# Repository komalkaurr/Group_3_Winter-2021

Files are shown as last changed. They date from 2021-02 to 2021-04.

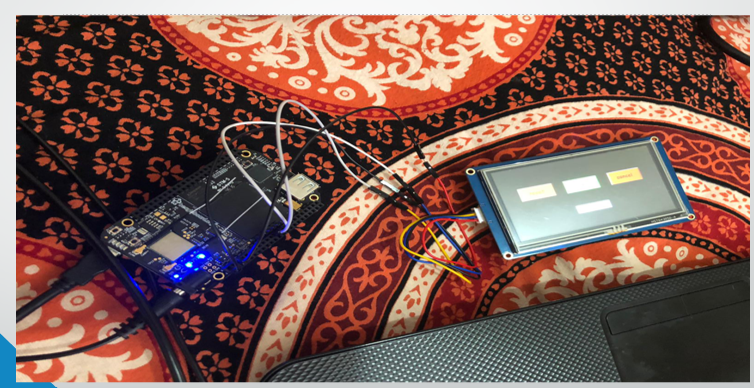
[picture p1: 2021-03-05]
Interfacing touch screen display/Connection .png

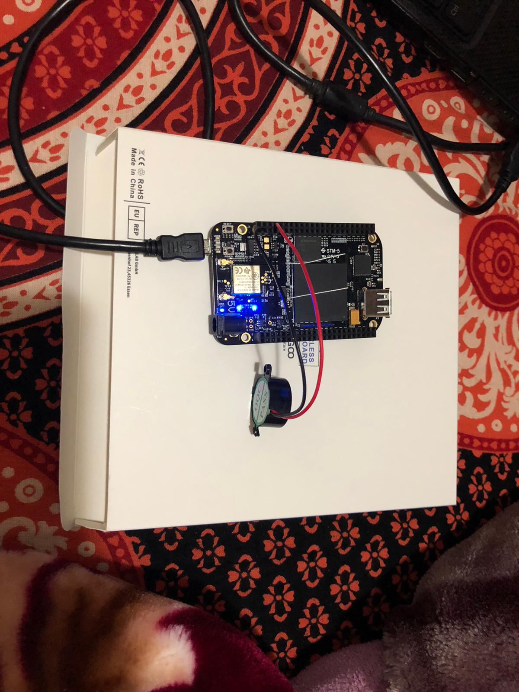
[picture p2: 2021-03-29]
Interfacing of buzzer with BB-WI/Connection.jpeg

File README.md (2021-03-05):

# Group_3_Winter-2021
EMBT Term 4 ESE_4009_2_Embedded Systems Engineering Project Group_3 

Group Members:
Komal Preet Kaur(c0765526)
Ramandeep Kaur(c0772741)
Amit Kumar(c0772515)
Ashok Kumar Saini(c0762216)
Sagar Pasricha(c0765531)
Virender Singh(c0762540)

EMBT is a core Embedded Sytems Design Course which prepare us for future in Embedded technology. In first 3 semesters, we learned about various theoretical aspects of Embedded Engineering and Design techniques. 
In 3rd semester, in ESE_3025 , we learned about real time operating systems and in ESE_3005,we learned about embedded systems architecture, LPC1769 board and MCUExpresso, various architectures such as mutex etc.Thus, we have learned about BBB and in 3014 ,we learned about various communication protocols and how to implement them with BBB to communicate with various devices. 
In term 4, we will make use of all the software and hardware skills in Capstone project. Our central device will be BB Wireless and we will make use of some real time problems in order to make a project which can tackle these issues to some extent.
In Term 4, we are going to design an IoT based smart restauranrt food ordering menu using Beaglebone black wireless.
Smart Restaurant food ordering menu using Beaglebone black.
1) Deciding and buying the components:
2) 2 Beaglebone
3) Arduino UNO
4) GSM module (SIM 900)
5) Xbee S2C RF module (Rx and Tx)
6) 20*4 LCD Module
7) 4.3" cape LCD touch screen (Nextion)
8) Breadboard/Zero PCB
9) 2 SD cards (32GB each)
10) Jumper wires
11) Power supply (Adapter)
12) Soldering Equipment (soldering iron, soldering wire)
13) Carbon Monoxide detection sensor 
14) Temperature Sensor (LM 35)
15) Smoke and LPG gas sensor (MQ-2)
16) Mct2e optocoupler
17) Buzzer
18)  Wire cutter
19) Wire stripper
20) 12v DC Fan
21) Power supply

**Testing hardware components:
After buying all hardware, first step is to test it so that we can use it in our project with no second thoughts. 

**So, I was assigned a task to test following components:

Arduino Uno: I tested Arduino Uno with blinking LED code avilable in Arduino IDE and also researched about Arduino IDE

20* 2 LCD module : For testing of LCD, I interfaced LCD module to Arduino Uno and imported I2C library to IDE and tested an example code from library

4.3" Nextion Touch display module: For testing of touch module, I created a simple GUI using Nextion editor and then in order to show data transfer between Arduino and touch LCD, 
I imported a code to Arduino IDE and uploaded it to Touch module and it worked properly.

Smoke sensor-MQ-2 : Testing of smoke sensor is done by interfacing it with arduino

CO sensor-MQ-9 : It is also interfaced to Arduino in order to do testing.

Magnetic Buzzer: Buzzer is also tested using a simple delay program in Arduino IDE

SIM900 GSM Module :I interfaced GSM Module to Arduino but it was not able to detect network , so testing was not completed.

I was able to test all components succesfully except GSM module. 

Next Task:
My task is about interfacing of touch screen dsiplay with Beaglebone Black Wireless.

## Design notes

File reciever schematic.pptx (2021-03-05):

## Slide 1

Designing circuit diagram and schematics for receiver side

Sagar Pasricha (C0765531)

## Different Software's used for circuit designing

- Circuit Maker
- Microsoft Visio
- Easy EDA
- Fritzing
- Eagle
- OrCAD
- gEDA
- SmartDraw
- KiCad
- CircuitLab
- XCircuit

## Easy EDA

- Easy EDA is a web based EDA tool that enables the hardware engineers to design, simulate, share and discuss schematics, simulations and printed circuit boards. Features may include Bill of Materials, Gerber files and pick and place files and documentary outputs in PDF, PNG and SVG formats.
- Most of the things, such as libraries, projects, custom-made parts, packages and shared files are accessible via a simple drop down menu at the top left side of the software interface. This makes it easy for you to navigate through the software regardless of whether you are beginner or pro.

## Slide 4

Beaglebone black wireless

Based on the extremely successful open-source BeagleBone Black hardware design, BeagleBone Black Wireless is a high-expansion, maker-focused, community-supported open hardware computer created by the BeagleBoard.org Foundation.
512MB DDR3 RAM
4GB 8-bit eMMC on-board flash storage
3D graphics accelerator
NEON floating-point accelerator
2x PRU 32-bit microcontroller

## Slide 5

Beaglebone black wireless

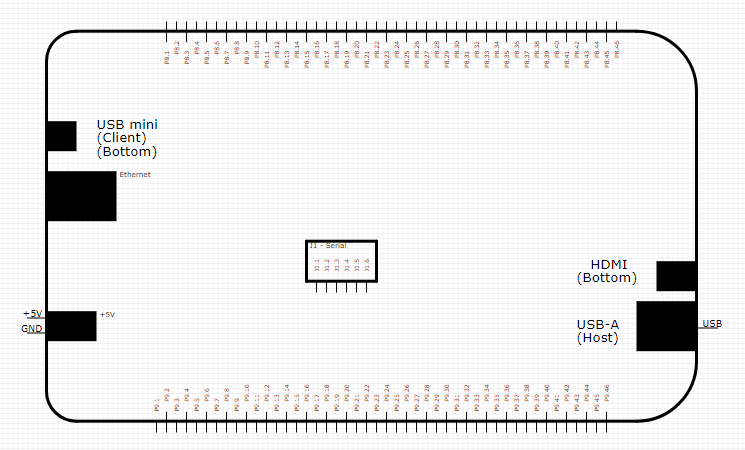
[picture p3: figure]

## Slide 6

Buzzer interfacing

For interfacing buzzer, GPIO pins of BBB are used.
A buzzer or beeper is an audio signaling device, which may be mechanical, electromechanical, or piezoelectric. Typical uses of buzzers and beepers include alarm devices, timers and confirmation of user input such as a mouse click or keystroke.

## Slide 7

Buzzer interfacing

BBB | Buzzer
1 (DGND) | -V
23 (GPIO_49) | +V

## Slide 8

Buzzer interfacing

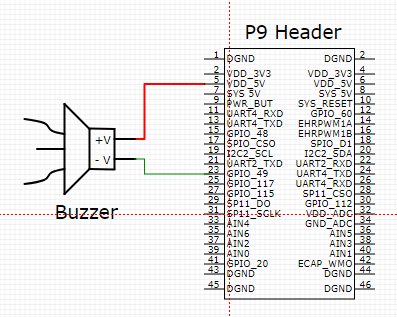
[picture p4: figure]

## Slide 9

Gas & SMOKE sensor interfacing

SPI or I2C protocol can be used to interface LPG sensor via GPIO pins of BBB. There is possible schematics where the gas sensor is connected to 5V power supply at a BeagleBone Black's analog input pin.

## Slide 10

Gas & SMOKE sensor interfacing

BBB | MQ2 Sensor
1 (DGND) | GND
5 (VDD 5V) | Vcc
33 (AIN4) | Vout

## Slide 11

Gas & SMOKE sensor interfacing

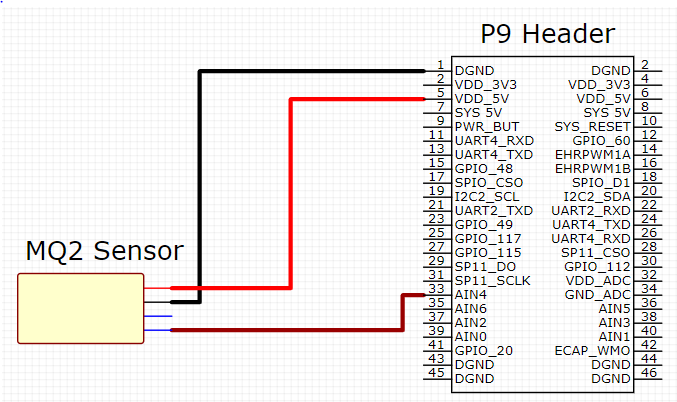
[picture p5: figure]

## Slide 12

GAS & smoke sensor interfacing

BBB | MQ6 Sensor
2 (DGND) | GND
6 (VDD 5V) | Vcc
36 (AIN5) | Vout

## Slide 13

GAS & smoke sensor interfacing

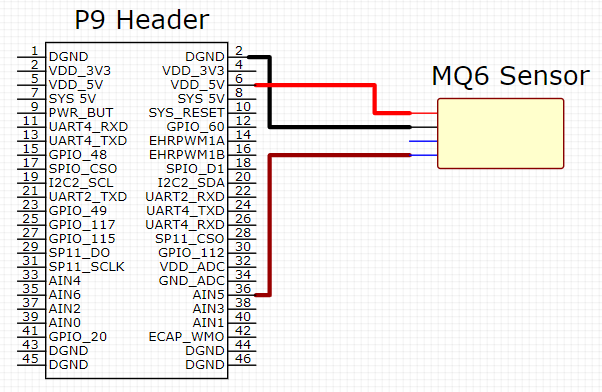
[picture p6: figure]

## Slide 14

temperature sensor
interfacing

LM35 is an analog sensor (Temperature Sensor) which measures the temperature and linear output given in voltage form. ADC is required to convert analog output of temperature sensor to digital output. Since BBB has an on chip ADC, we can directly interface these two.

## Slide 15

temperature sensor
interfacing

BBB | LM35 Sensor
1 (DGND) | GND
5 (VDD +5V) | Vcc
38 (AIN3) | Vout

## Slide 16

temperature sensor
interfacing

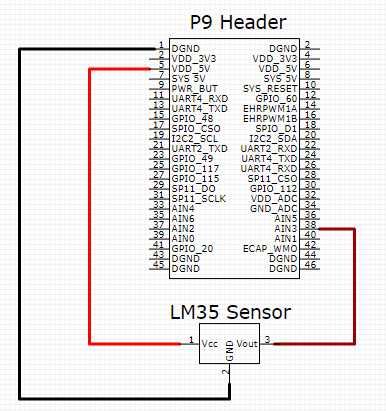
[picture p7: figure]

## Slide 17

dc fan interfacing

One of the GPIO pin of BBB is connected to the Opto-coupler’s photodiode pin which lets the inner circuit to switch on (closed circuit) and we can connect the other end to the Fan.

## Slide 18

dc fan interfacing

BBB | Optocoupler | DC Fan
15 (GPIO_48) | 1 (Photodiode)
45 (DGND) | 2 (Photodiode)
| 4 (Vout) | Red
| 5 (+9V)

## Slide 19

dc fan interfacing

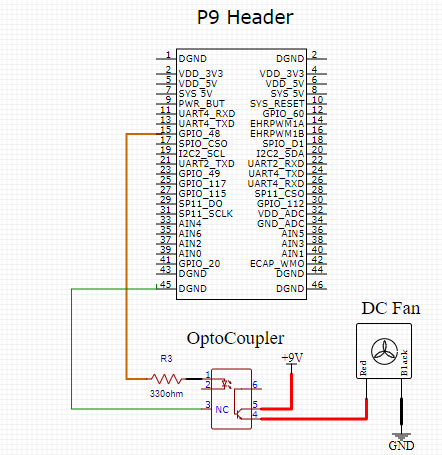
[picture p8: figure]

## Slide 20

Xbee interfacing

For a microcontroller based project, communication is necessary between devices. In our project we need two-way communication, so we use XBee trans-receiver which can transmit and receive data at the same time.

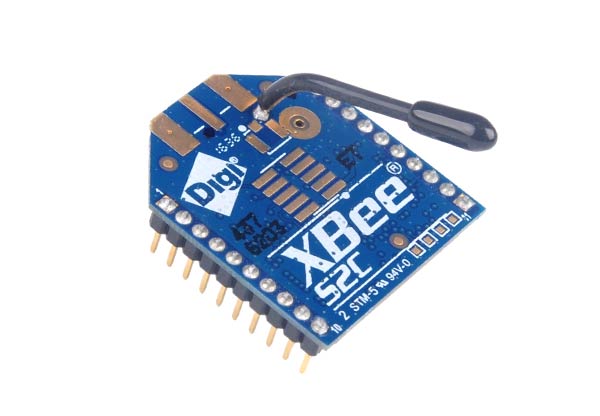
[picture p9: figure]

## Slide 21

Xbee interfacing

Pin Interface with Beaglebone Balck Wireless:

BBB | XBee
6 (Vdd +5V) | 1 (Vcc)
22 (UART_RxD) | 2 (Dout)
24 (UART4_TxD | 3 (Din)
46 (DGND) | 10 (GND)

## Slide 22

Xbee interfacing

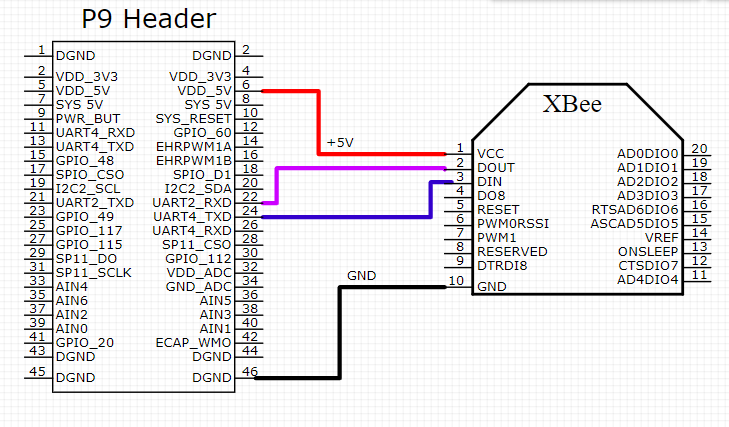
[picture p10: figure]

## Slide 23

Gsm module interfacing

The SIM900 is a complete Quad-band GSM/GPRS solution in a SMT module which can be embedded in the customer applications. Featuring an industry standard interface, the SIM900 delivers GSM/GPRS 850/900/1800/1900MHz performance for voice, SMS, data and fax.
SIM900 is designed with a very powerful single-chip processor integrating AMR926EJ-S core
We have interfaced GSM module to Beaglebone via Arduino.

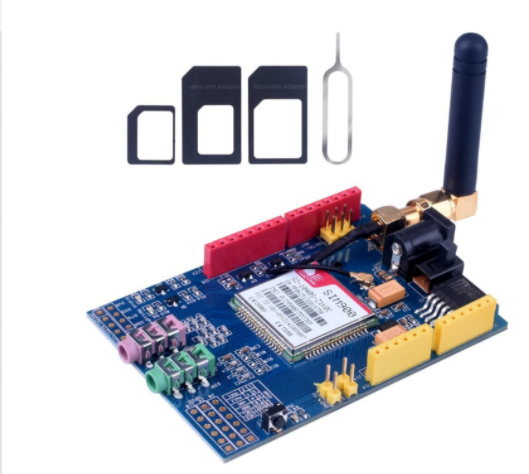
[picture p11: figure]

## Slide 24

Gsm module interfacing with arduino

Arduino | GSM Module
D_0 | TX (Transmitter)
D_1 | Rx (Receiver)
GND2 | GND
5V | 5V

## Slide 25

Arduino interfacing with Beaglebone:

Arduino | Beaglebone
D_6 | 26(UART_4RXD)
D_7 | 24(UART_4TXD
GND2 | GND
5V | 5V

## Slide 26

Gsm module interfacing

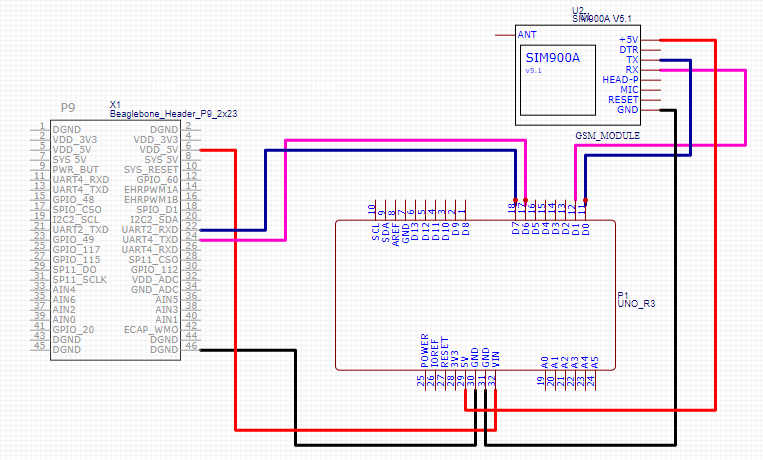
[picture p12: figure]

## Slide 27

I2c lcd interfacing

LCD (Liquid Crystal Display), In order to interface BBB to LCD ,GPIO pins of Beaglebone are used. Before installing the character LCD library you'll need to make sure a few dependencies are installed On the BeagleBone Black.
Firstly, we need to interface I2C module with Beaglebone Black wireless including supply voltage.
Then LCD is connected to I2C module including supply and data pins.

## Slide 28

I2c lcd interfacing

BBB | I2C Module
2 (DGND) | 17 (GND)
6 (Vdd +5V) | 18 (Vcc)
19 (I2C2_SCL) | 19 (SDA)
20 (I2C2_SDA) | 20 (SCL)

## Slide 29

I2c lcd interfacing

I2C Module | LCD
1 (VSS) | 1 (VSS)
2 (VDD) | 2 (VDD)
3 (V0) | 3 (V0)
4 (RS) | 4 (RS)
5 (R/W) | 5 (R/W)
6 (E) | 6 (E)
7-14 (DB0-DB7) | 7-14 (DB0-DB7)
15 (A) | 15 (BLA)
16 (K) | 16 (BLK)

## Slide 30

I2c lcd interfacing

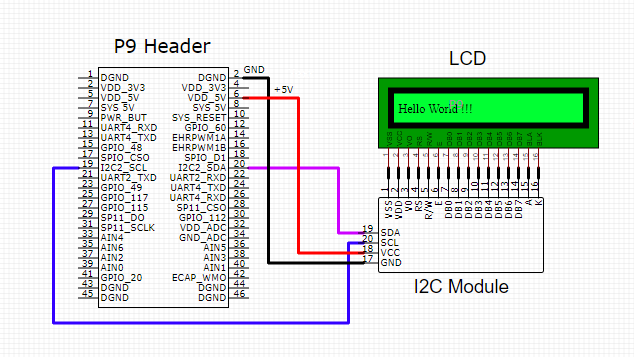
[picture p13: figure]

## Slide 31

Receiver circuit

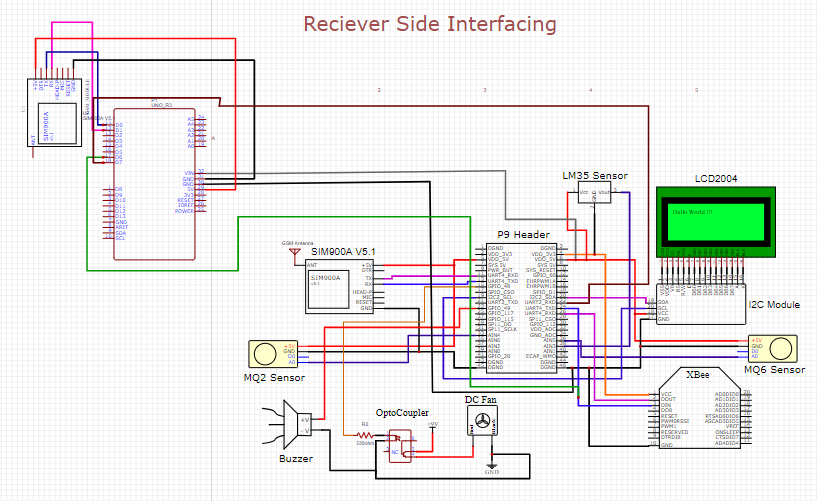
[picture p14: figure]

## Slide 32

references

- EasyEDA tutorial. Retrieved from easyeda.com: https:// (https://docs.easyeda.com/en/FAQ/Editor/index.html)docs.easyeda.com/en/FAQ/Editor/index.html
- turn on-off a 12V cpu fan with optocoupler. (n.d.). Retrieved from stackexchange.com: https:// (https://electronics.stackexchange.com/questions/154119/arduino-turn-on-off-a-12v-cpu-fan-with-optocoupler)electronics.stackexchange.com/questions/154119/arduino-turn-on-off-a-12v-cpu-fan-with-optocoupler
- MQ2 Gas Sensor. (2018, jan 04). Retrieved from components101.com: https:// (https://components101.com/mq2-gas-sensor)components101.com/mq2-gas-sensor
- DiCola, T. (n.d.). Character LCD with Raspberry Pi or BeagleBone Black. Retrieved from www.digikey.ca: https:// (https://www.digikey.ca/en/maker/projects/character-lcd-with-raspberry-pi-or-beaglebone-black/3990178769cf4d2293f1a19993873f05)www.digikey.ca/en/maker/projects/character-lcd-with-raspberry-pi-or-beaglebone-black/3990178769cf4d2293f1a19993873f05
- Interfacing to the Beagle Board optocoupler Input/Outputs. (n.d.). Retrieved from exploringbeaglebone.com: http:// (http://exploringbeaglebone.com/chapter6/)exploringbeaglebone.com/chapter6/
- Measure Temperature using LM35 Interfacing with Beaglebone black. (n.d.). Retrieved from engineersgarage.com: https:// (https://www.engineersgarage.com/electronic-projects/measure-temperature-using-lm35-interfacing-with-beaglebone-black-part-15-15/)www.engineersgarage.com/electronic-projects/measure-temperature-using-lm35-interfacing-with-beaglebone-black-part-15-15/
- XBee S2C ZigBee (Wire Antenna). (n.d.). Retrieved from elediy.com: https:// (https://elediy.com/products/xbee-s2c-zigbee-wire-antenna)elediy.com/products/xbee-s2c-zigbee-wire-antenna
- Zigbee Wireless Mesh Networking. (n.d.). Retrieved from www.digi.com: https:// (https://www.digi.com/solutions/by-technology/zigbee-wireless-standard)www.digi.com/solutions/by-technology/zigbee-wireless-standard
- GSM Module Interfacing. (n.d.). Retrieved from rhydolabz.com: https://www.rhydolabz.com/wiki/?p=10450

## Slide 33

Any questions?

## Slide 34

Thank you

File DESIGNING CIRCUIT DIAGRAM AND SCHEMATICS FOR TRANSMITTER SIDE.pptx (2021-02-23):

## DESIGNING CIRCUIT DIAGRAM AND SCHEMATICS FOR TRANSMITTER SIDE Presented by :- Virender Singh (C0762540)

## What is Schematics?

- It is the representation of the element of the system using abstract, graphic symbols rather than realistic pictures. It can provide the details that are not relevant to the key information. It may include oversimplified elements in order to make this essential meaning easier.
- In an electronic circuit diagram the layout of symbols may not look anything like the circuit as it appears in the physical world but instead the schematic aims to capture on more general level the way it works

## Use of Schematics in Electrical and Electronic Industry

- Schematics in Electrical and electronics industry is often used to describe the design of the equipment. They are often used for the maintenance and repair of electronic and electromechanical systems. Earlier the schematics were done by hand using standardized templates but nowadays they are mostly done using Electronic Design Automation software (EDA).
- Until 1980s the schematics were the only formal representation for the circuits but with the recent technology, other representations were introduced and specialized computer languages were developed so the traditional schematics are becoming less practical.

## Uses of Schematics in Electrical and Electronics Industry

- For electronic circuits the schematics are prepared by designers using EDA (Electronic Design Automation) tools known as Schematic capture tools or Schematic entry tools. Usually they are integrated into whole design flow and are linked to the other EDA tools for verification and simulation of circuit under design.
- Programmable Logic Controllers (PLC) can be programmed using ladder diagrams.

## Use of Schematics in Electronic and Electrical Industry

- In electric power systems design, a schematic drawing called as one line diagram is frequently used to represent substations, distribution systems or even whole electrical power grids. In these diagrams they simplify and compress the details that would be repeated on each phase of a three phase system, showing only one element instead of three. Another type of diagram used for power systems is three line diagram.

## Uses of Schematics in Electronic and Electrical Industry

- For one line diagram, if the system is balanced an equivalent per phase schematic diagram can be obtained. If all of parameters are represented as impedances and voltage sources then that schematic diagram is called Impedance diagram but if parameters are represented as admittances and current sources then it is called Admittance diagram.
- If power system is unbalanced but it is linear then Fortescue theorem can be applied. In this way from one linear diagram, three different per phase schematic diagrams are obtained known ass Positive, Negative and Zero sequence diagram.

## Softwares used for Schematics

- 1- Circuit Maker
- 2- Microsoft Visio
- 3- Easy EDA
- 4- Fritzing
- 5- Eagle
- 6- OrCAD
- 7- gEDA
- 8- SmartDraw
- 9- KiCad
- 10- CircuitLab
- 11- XCircuit

## Fritzing Software

- Fritzing is an open source initiative used for developing CAD software for the design of electronics hardware to support designers to move from experimenting with prototype to building a more permanent circuit. It is basically seen as EDA tool for non- engineers.

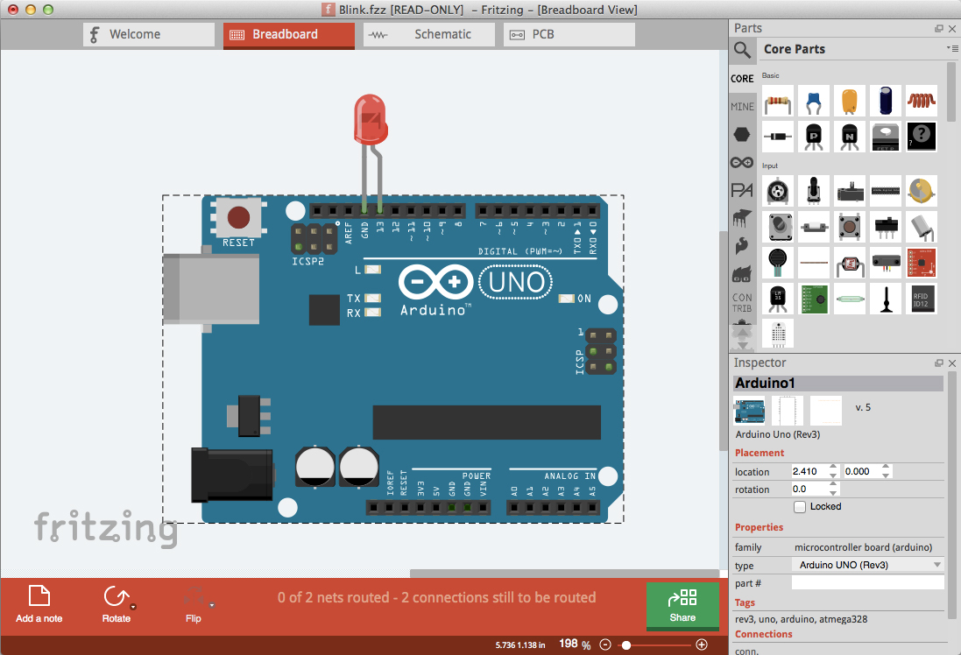
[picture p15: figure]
Fritzing - Wikipedia

## Goals of Fritzing Software

- It is mainly created for processing programming language and Arduino microcontroller. It allows the designer to document their Arduino based prototype and create a PCB layout for manufacturing.
- It can be seen as EDA tool as the input metaphor is inspired by the environment of designers while the output is focused on accessible means of production.
- It has code view option where we can modify code and upload it directly to an Arduino device.

## How to install Fritzing?

- Go on google and search Fritzing
- We will see that for installing the Fritzing application they will be charging 6 to 8 euros.
- Then we will have to search for the link from where we can download the software free of cost.
- Then click on this link https://www.electroschematics.com/fritzing-software-download/
- After clicking on this link we can install Fritzing free of cost.

## Easy EDA

- Easy EDA is a web based EDA tool that enables the hardware engineers to design, simulate, share and discuss schematics, simulations and printed circuit boards. Features may include Bill of Materials, Gerber files and pick and place files and documentary outputs in PDF, PNG and SVG formats.

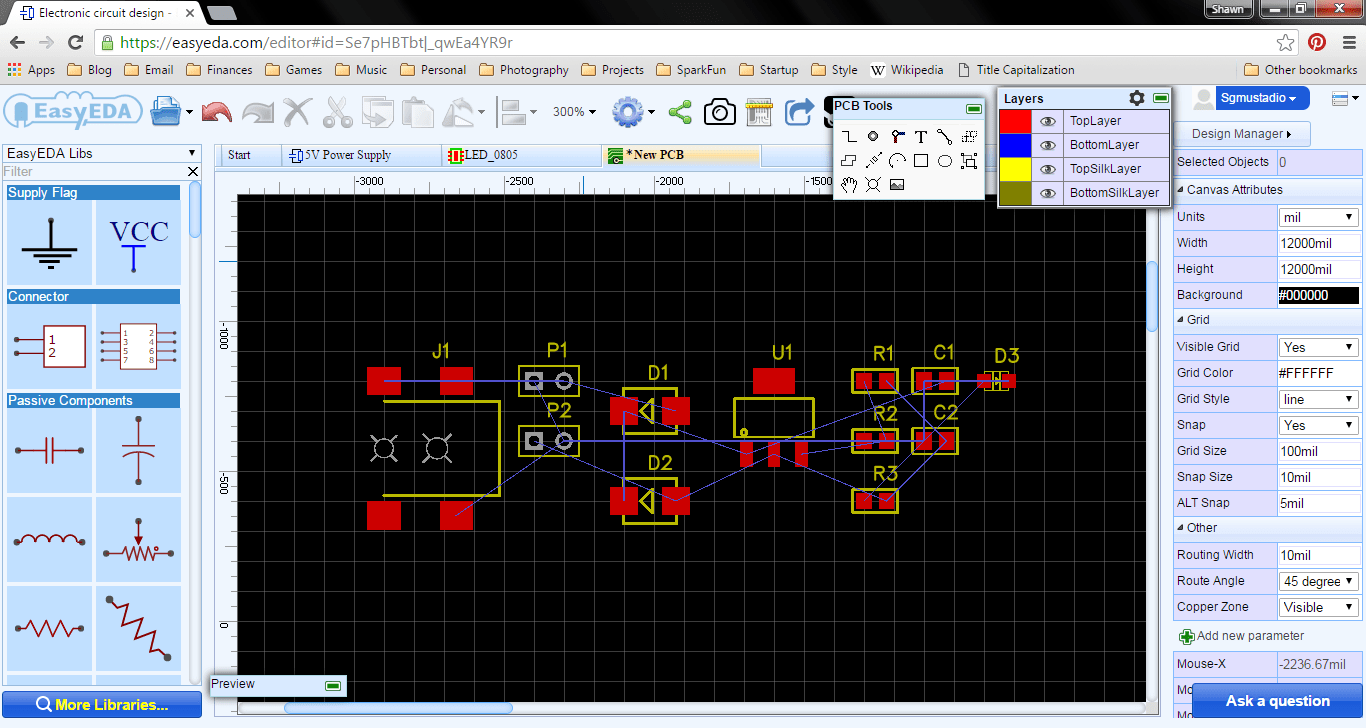
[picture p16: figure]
Getting Started with EasyEDA Part 3: PCB Layout - EasyEDA

## How to install EasyEDA ?

- For installing EasyEDA we have to follow these simple steps:
- Go on google and search https://www.google.com/search?client=firefox-b-d&q=EasyEDA
- Then click on above link and click on EasyEDA
- Then click on install button for downloading EasyEDA
- If you don’t want to install EasyEDA in your laptop just click on EasyEDA designer. https://easyeda.com/editor
- Here on clicking the above link just you can start there using it for free or we can perform our work online.

## CircuitMaker

- It is an electronic design automation software for the printed circuit board designs targeted at hacker and maker community. The hardware designed with it may be used for commercial and non commercial purposes without limitation. It also supports design rule configuration and real time design rule checking.

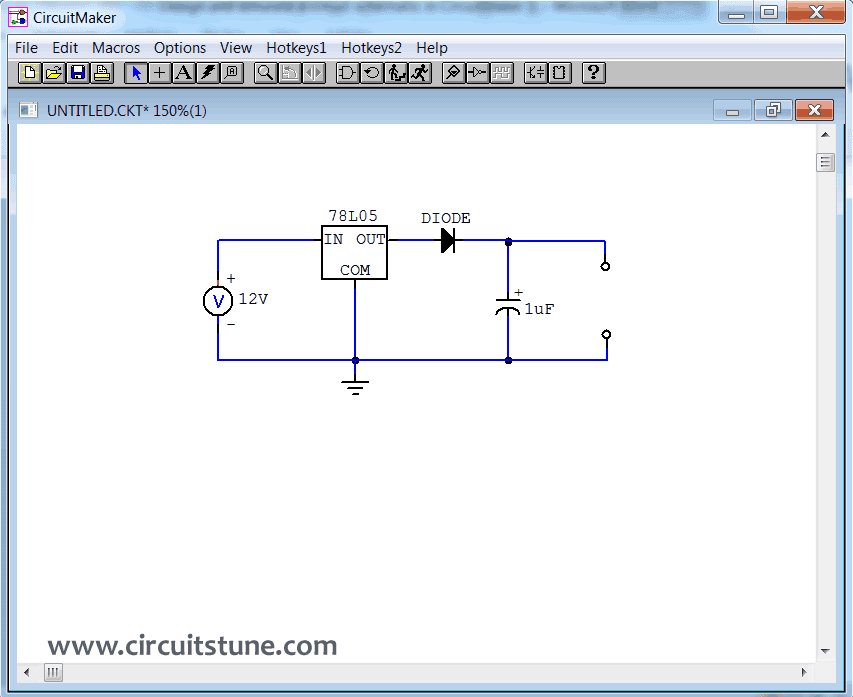
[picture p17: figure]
Circuit Maker Pcb Tutorial - Circuit Boards

## Microsoft Visio

- It is an diagramming and vector graphics application. It is basically available in two editions such as Standard and Professional. The standard and professional edition share same interface but professional edition has additional templates for more advanced diagrams and layout
- Professional edition features three additional diagram types as well as rules, validation and subprocess.
- It is also offered as an additional component of an Office365 subscription.

## Eagle

- Eagle stands for Easily Applicable Graphical Layout Editor.
- It is an scriptable electronic design automation with schematic capture, printed circuit board layout, auto-router and computer aided manufacturing features.
- It also provides multi window graphical user interface and menu system for editing, project management and to customize the interface and design parameters.
- It saves Gerber and Postscript layout files as well as Excellon and Sieb & Meyer drill files.

## OrCAD

- It is basically a software tool used primarily for electronic design automation. It is used to create electronics schematics and perform mixed signal simulation and electronic prints for manufacturing printed circuit board.
- The name OrCAD reflects the company and its software origins Oregon+CAD

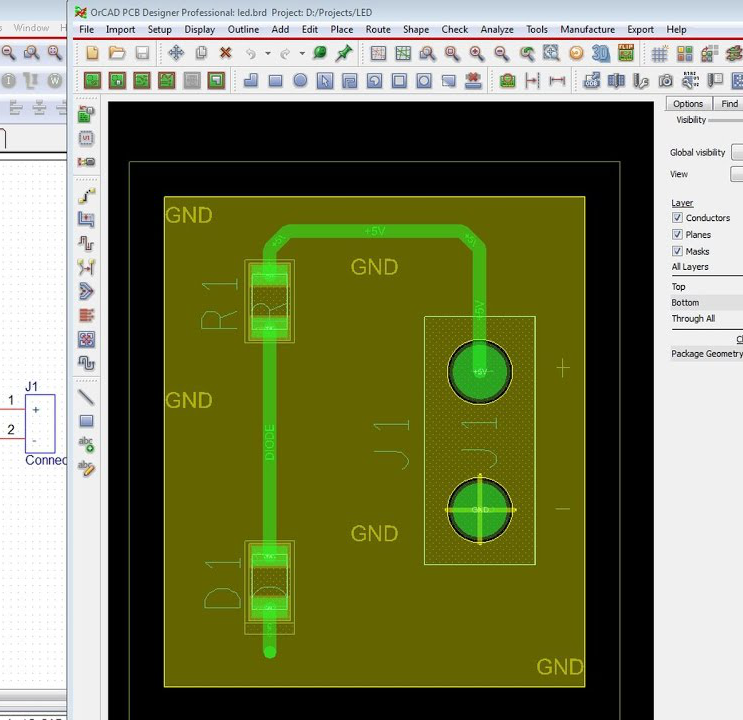
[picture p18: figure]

## gEDA

Geda is an ECAD or EDA application suite. It is mostly oriented towards printed circuit board design.
The word Geda is a conjunction of GPL and EDA. The names of some of the individual tools in the gEDA suite are prefixed with letter g to emphasize that they are released under the General Public License.

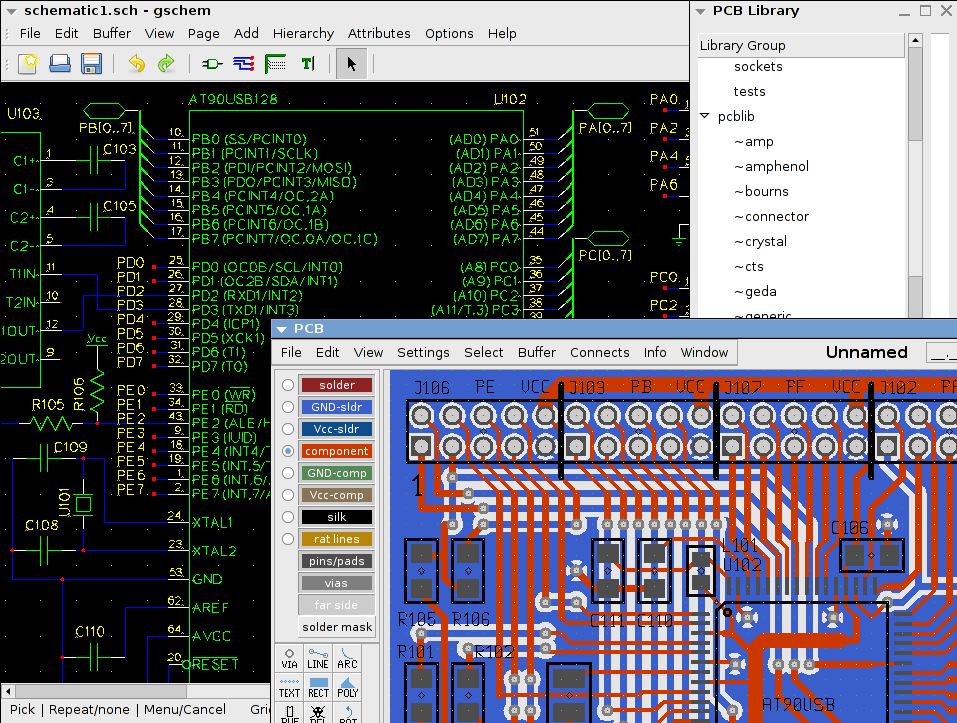
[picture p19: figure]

## SmartDraw

- It is an diagram tool used to make flowcharts, organizations charts, mind maps, project charts and other business visuals.
- It has two versions : Online Edition and a downloadable edition for Windows desktop.
- It integrates with Microsoft office products including Word, Powerpoint and Excel and applications like Google Docs and Google Sheets.
- It is compatible with Google Drive, Dropbox, Box and Onedrive.

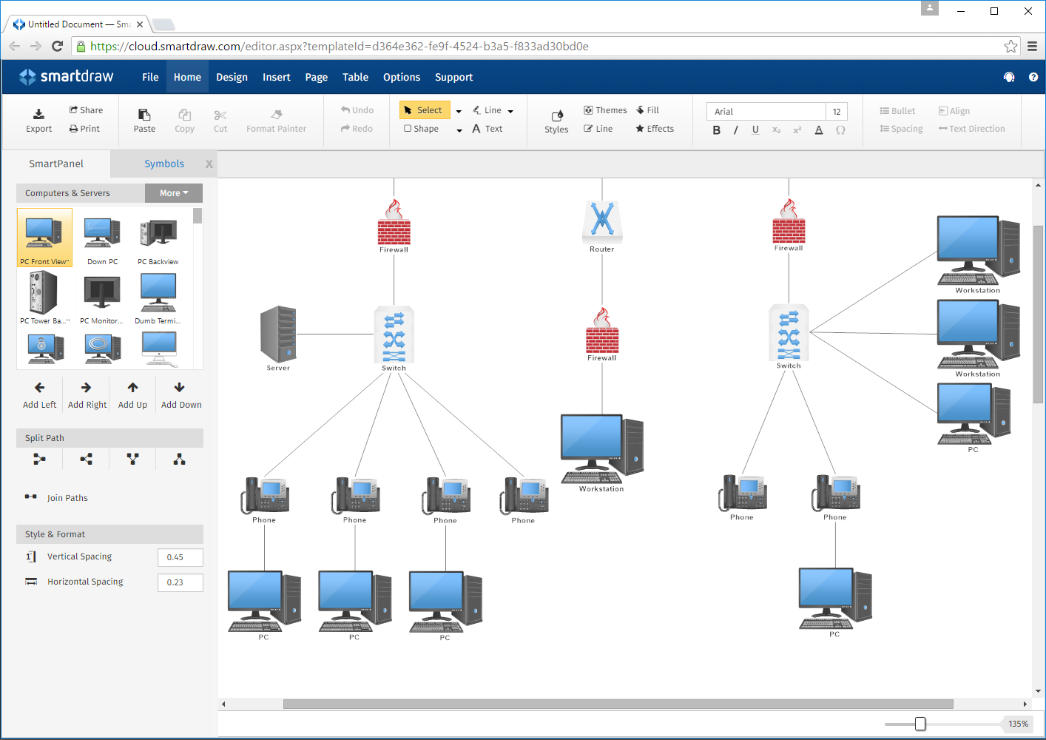
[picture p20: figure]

## KiCad

- It is free software for electronic design automation. It facilitates the design of schematics for electronic circuits and their conversion to PCB designs.
- It features an integrated environment for schematic capture and PCB layout design. Tool exist within the package to create a bill of materials, artwork, Gerber files, and 3D views of the PCB and its components.
- It is integrated for all stages of design process such as schematic capture, PCB layout, Gerber file generation and library editing.

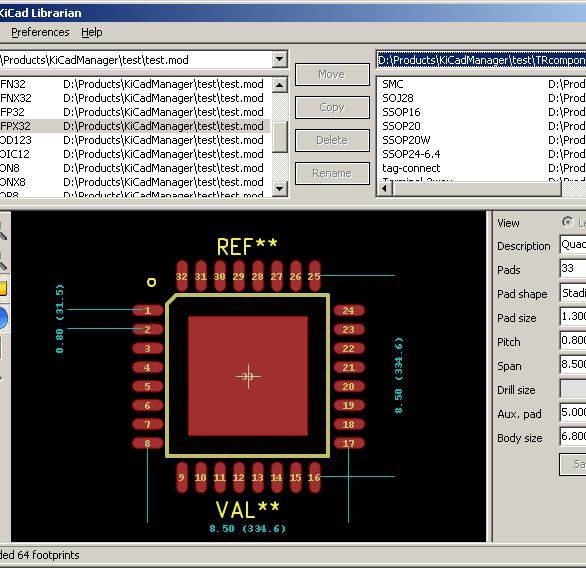
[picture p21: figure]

## CircuitLab

- It is platform that makes it easy for engineering, hobbyists and students to design, build and share circuits.
- It was designed to be web app that could be utilized by electrical design engineers to draw and simulate a circuit without reading complicated legacy desktop software or any manual.

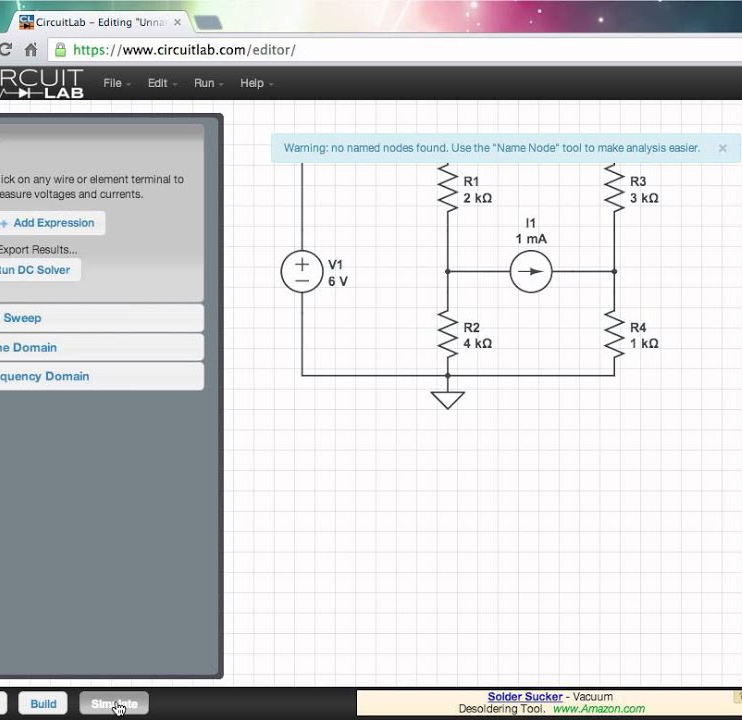
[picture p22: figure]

## XCircuit

- Xcircuit is used for drawing electrical schematics diagrams and related figures and production of circuit netlists through schematics capture.
- It maintains flexibility in style without compromising the power of schematic capture.
- Circuit components are saved in and retrieved from libraries which are fully editable.

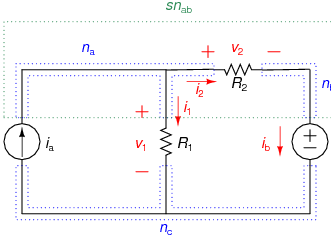
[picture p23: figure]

## Fritzing

- Fritzing is an open-source initiative to develop amateur or hobby CAD software for the design of electronics hardware, to support designers and artists ready to move from experimenting with a prototype to building a more permanent circuit.
- The software is created in the spirit of the Processing programming language and the Arduino microcontroller[5] and allows a designer, artist, researcher, or hobbyist to document their Arduino-based prototype and create a PCB layout for manufacturing.
- The associated website helps users share and discuss drafts and experiences as well as to reduce manufacturing costs.

## Concept About Fritzing

- Breadboard View – Fritzing can present your circuit in breadboard view, making it easy to visualize how components will fit together and be wired together. Fritzing has a vast library of parts to represent all major components in the Breadboard view.
- Schematic View – This is the traditional view of the circuit as represented in books. Frtizing has a large library of schematic parts to build up the Schematic View.
- Printed Circuit Board View – A printed circuit board (PCB) consists of electronic components connected electrically on copper tracks laminated on a non-conducting substrate. This view is necessary to fabricate the PCB for the circuit.

## Importing Libraries

- Importing Beaglebone black libraries
- Go to this website and click the 'View Raw' button to download the latest AdaFruit library.
https://github.com/adafruit/Fritzing-Library/blob/master/AdaFruit.fzbz
- At the top left of the Fritzing application, click: File>Open>AdaFruit.fzbz
- Once the library is imported, exit the Fritzing library. You will be prompted with a box. Make sure to save the changes to your library.

## Importing Libraries for LCD touch

- https://fritzing.org/projects/nextion-display
- Go to the above link and download *fzz file for Nextion Touch display
- Add libraries to the fritzing app
- Exit
- Relaunch

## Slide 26

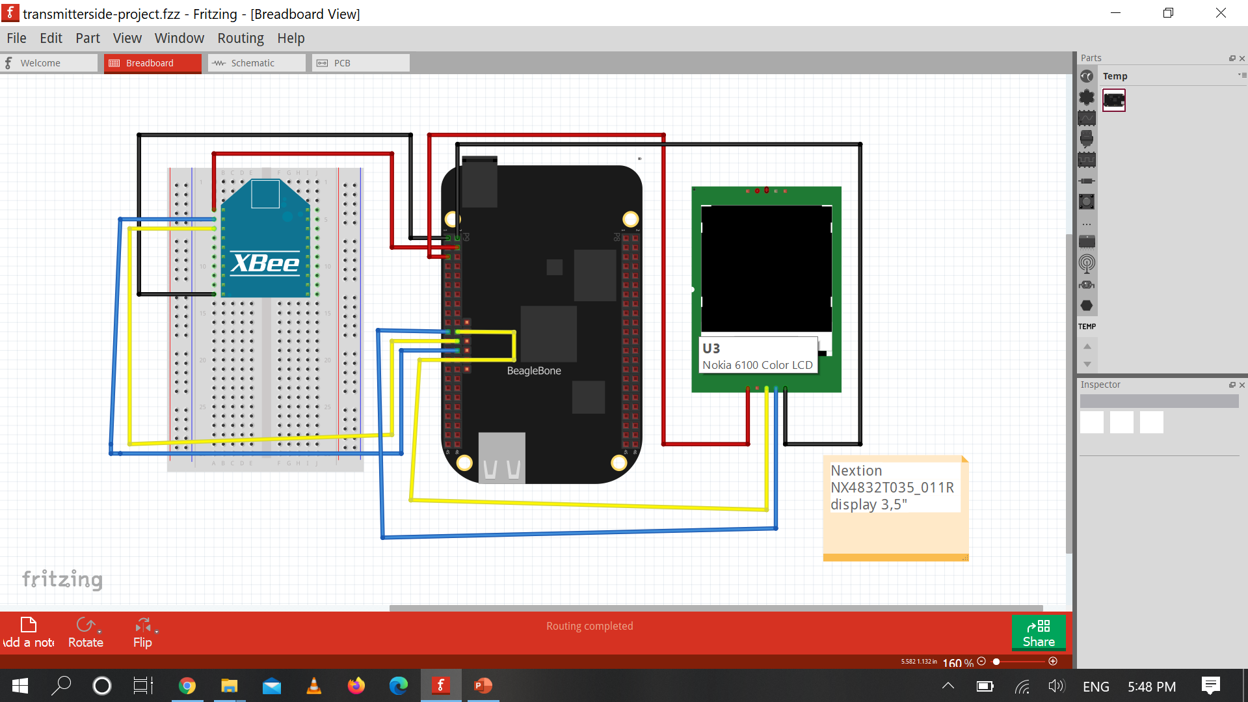
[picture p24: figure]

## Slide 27

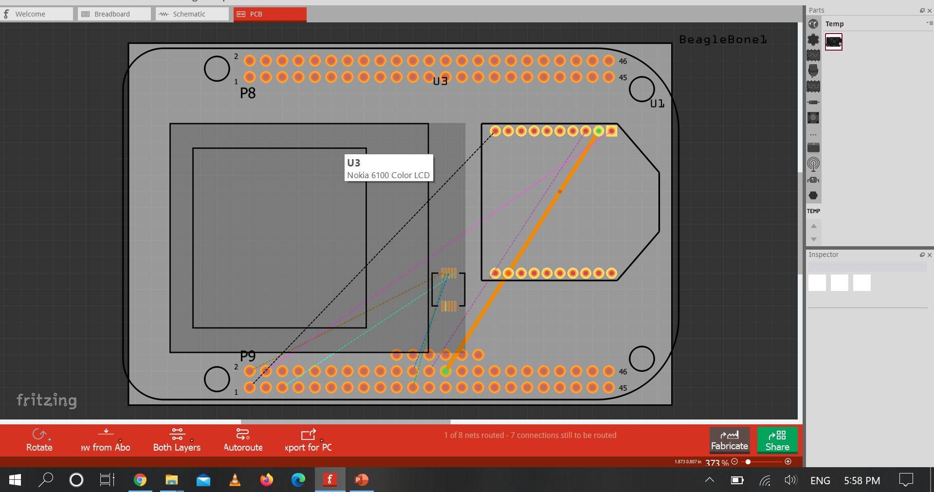
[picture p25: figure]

## Refrences

- https://en.wikipedia.org/wiki/Schematic...Schematics
- https://www.seeedstudio.com/blog/2017/03/13/pcb (https://www.seeedstudio.com/blog/2017/03/13/pcb-design-software/)-design-software/ (https://www.seeedstudio.com/blog/2017/03/13/pcb-design-software/).... Softwares for Schematics
- https://www.pannam.com/blog/best- (https://www.pannam.com/blog/best-pcb-design-software-tools/....Softwares)pcb (https://www.pannam.com/blog/best-pcb-design-software-tools/....Softwares)-design-software-tools/.... (https://www.pannam.com/blog/best-pcb-design-software-tools/....Softwares)Softwares (https://www.pannam.com/blog/best-pcb-design-software-tools/....Softwares) for schematics
- https://en.wikipedia.org/wiki/Fritzing.....Fritzing
- https://en.wikipedia.org/wiki/EasyEDA......EDA

## Refrences

- https://en.wikipedia.org/wiki/CircuitMaker
- https://en.wikipedia.org/wiki/Microsoft_Visio
- https://en.wikipedia.org/wiki/EAGLE_(program)
- https://en.wikipedia.org/wiki/GEDA
- https://en.wikipedia.org/wiki/SmartDraw
- https://fritzing.org/projects/nextion-display ...Importing libraries for LCD Touch
https://github.com/ (https://github.com/adafruit/Fritzing-Library/blob/master/AdaFruit.fzbz....Importing)adafruit (https://github.com/adafruit/Fritzing-Library/blob/master/AdaFruit.fzbz....Importing)/Fritzing-Library/blob/master/ (https://github.com/adafruit/Fritzing-Library/blob/master/AdaFruit.fzbz....Importing)AdaFruit.fzbz (https://github.com/adafruit/Fritzing-Library/blob/master/AdaFruit.fzbz....Importing)....Importing (https://github.com/adafruit/Fritzing-Library/blob/master/AdaFruit.fzbz....Importing) libraries

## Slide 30

ANY QUESTIONS ???
THANK YOU

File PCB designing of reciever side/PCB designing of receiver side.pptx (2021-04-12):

## IOT Based Smart Restaurant Menu Using BB-WI

Task
PCB Designing of Receiver Side
Submitted to:
Prof. Mike Aleshams
Submitted by:
Ramandeep Kaur
Group 3

## PCB

- A printed circuit board mechanically supports and electrically connects electrical or electronic components using conductive tracks,pads and other features etched from one or more sheet layers of copper laminated onto and or between sheet layers of a non-conductive substrate. Components are generally soldered onto the PCB to both electrically connect and mechanically fasten them to it.

## Softwares for PCB Designing

- EasyEda
- PROTEL(Altium designer)
- PADS
- ORCAD
- Fritzing
- Kicad
- Allegro
- And some more………

## EasyEDA

- EasyEDA is an easier and powerful online PCB design tool that allows electronics engineers, educators, students, makers, and enthusiasts to design and share their projects.Some features of EasyEDA,Bill of Materials, Gerber files and pick and place files and documentary outputs in PDF, PNG and SVG formats,

## Components

- Beaglebone Black Wireless
- Buzzer
- XBee module
- MQ 9 Sensor
- MQ 2 Sensor
- Temperaturen Sensor
- Opto-coupler
- Fan
- Node MCU
- LCD display

## Communication Protocol

- UART (Universal asynchronous receiver-transmitter)
  - XBee Module
  - Node MCU
- GPIO (General purpose input/output)
  - Buzzer
  - LPG Gas & Smoke Sensor
  - CO Sensor
  - Temperature Sensor
  - Opto-coupler
  - LCD Display

## Beaglebone Black Wireless

- Based on the extremely successful open-source Beaglebone Black hardware design, Beaglebone Black Wireless is a high-expansion, maker-focused, community-supported open hardware computer created by the BeagleBoard.org Foundation.

## Pin Description of BB-WI

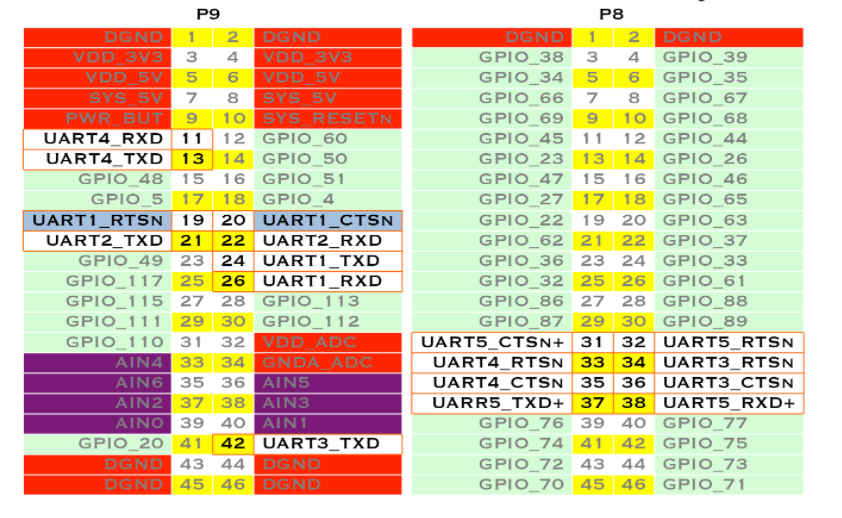
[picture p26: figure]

## Xbee Module

- XBee S2C is a RF module designed for wireless communication or data exchange and it works on ZigBee mesh communication protocols.The module provides wireless connectivity to end-point devices in any ZigBee mesh networks including devices from other vendors.

## Pin Diagram of Xbee Module


## Pin Description of Xbee Module

Pin | Name | Description
1 | VCC | Power supply
2 | DOUT/DIO13 | UART data out pin (TXD)/GPIO
3 | DIN/CONFIG / DIO14 | UART data in pin (RXD)/ GPIO
4 | DIO12/SPI_MISO | GPIO/ Master Input-Slave Output pin of SPI interface
5 | RESET | Module Reset pin

## Pin Description of Xbee Module

Pin | Name | Description
6 | RSS PWM /DIO10 | RX Signal Strength Indicator pin / GPIO
7 | PWM1/DIO11 | Pulse Width Modulator/GPIO
8 | RESERVED | Do not connect
9 | DTR/SLEEP_RQ/ DIO8 | Pin Sleep Control line /GPIO
10 | GND | Ground

## Pin Description of Xbee Module

Pin | Name | Description
11 | DIO4/ SPI_MOSI | GPIO/Master Output-Slave Input pin of SPI interface
12 | CTS/DIO7 | Clear-to-send flow control/GPIO
13 | ON_SLEEP/DIO9 | Device status indicator/GPIO
14 | VREF | Voltage Reference for ADC
15 | ASC/DIO5 | Associate Indicator/GPIO

## Pin Description of Xbee Module

Pin | Name | Description
16 | RTS/DIO6 | Request to send flow control/ GPIO
17 | AD3/DIO3/SPI_SSEL | Analog input/GPIO/SPI slave select
18 | AD2 /DIO2/SPI_CLK | Analog input/GPIO/SPI clock
19 | AD1/DIO1/SPI_ATTN | Analog input/GPIO/SPI attention
20 | AD0/DIO0/C | Analog input/GPIO/ Commissioning button

## Interfacing of Xbee Module with BB-WI

XBee Module | BB-WI(P9 Header)
Pin 1(Vcc) | Pin 4(Vdd)
Pin 10(GND) | Pin 46(GND)
Pin 2(Dout) | Pin 26 (UART1_Rx)
Pin 3(Din) | Pin 24(UART1_Tx)

## Interfacing of Xbee Module with BB-WI


## NodeMCU ESP8266

- The NodeMCU ESP8266 development board comes with the ESP-12E module containing ESP8266 chip having Tensilica Xtensa 32-bit LX106 RISC microprocessor. This microprocessor supports RTOS and operates at 80MHz to 160 MHz adjustable clock frequency

## Pin diagram of NodeMCU ESP8266


## Interfacing of NodeMCU ESP8266 with BB-WI

NodeMCU ESP8266 | Beaglebone Black Wireless
3.3V | P9_3(VDD_3V3)
GND | P9_1(DGND)
Tx | P9_26(UART1_RxD)
Rx | P9_24(UART1_TxD)

## Buzzer

- A buzzer or beeper is an audio signaling device, which may be mechanical ,electromechnical or piezoelectric. Typical uses of buzzers and beepers include alarm devices, timers and confirmation of user input such as a mouse click or keystroke.

## Interfacing of Buzzer with Beaglebone Black Wireless

- Red wire(+ve) of buzzer connected to 23rd pin(GPIO_49) of P9 header of BB-WI.
- Black wire(Ground) of buzzer connected to 1st pin(DGND) of P9 header of BB-WI.

## Interfacing of Buzzer with Beaglebone Black Wireless


## MQ 2 Sensor

- MQ2 gas sensor is an electronic sensor used for sensing the concentration of gases in the air such as LPG, propane, methane, hydrogen, alcohol ,smoke and carbon monoxide.

## Interfacing of MQ 2 sensor with BB-WI

BB-WI(P9 Header) | MQ 2 Sensor
1(DGND) | GND
5(VDD 5V) | Vcc
33 (AIN4) | Vout

## Interfacing of MQ 2 sensor with BB-WI


## MQ 9 Sensor

- A gas sensor is a device which detects the presence or concentration of gases in the atmosphere. Based on the concentration of the gas the sensor produces a corresponding potential difference by changing the resistance of the material inside the sensor, which can be measured as output voltage. Based on this voltage value the type and concentration of the gas can be estimated.

## Interfacing of MQ 9 sensor with BB-WI

BB-WI(P9 Header) | MQ 9 Sensor
2 (DGND) | GND
6 (VDD 5V) | Vcc
36 (AIN5) | Vout

## Interfacing of MQ 9 sensor with BB-WI


## Temperature Sensor

- LM35 is an analog sensor (Temperature Sensor) which measures the temperature and linear output given in voltage form. ADC is required to convert analog output of temperature sensor to digital output. Since BBB has an on chip ADC, we can directly interface these two.

## Interfacing of Temperature sensor with BB-WI

Temperature Sensor | BB-WI (P9 Header)
GND | 1 (DGND)
Vcc | 5 (VDD 5V)
Vout | 38 (AIN3)

## Interfacing of Temperature sensor with BB-WI


## MCT2E Opto-coupler

- MCT2E is a phototransistor Optocoupler, as the name “phototransistor” suggests it has a transistor which is controlled based on light (photon).this IC basically has an IR (infrared) LED and a photo-transistor inside it. When the IR led is powered the light from it falls on the transistor and it conducts.

## Interfacing of MCT2E Optocoupler with BB-WI

- Pin no 1 of MCT2E with gpio_67 pin 8 of P8 header of Beagle bone black wireless.
- Pin no 2 of MCT2E with DGND pin 1/2 of P9 header of Beagle bone black wireless.
- Pin no 4 of MCT2E with GND of Breadboard
- Pin no 5 of MCT2E with positive (red wire) of DC fan.

## LCD Display(20*4)

- LCD stands for Liquid Crystal Display. It is basically a screen that is used as an electric display module which has various range of applications. Most commonly used module is 16*2 LCD display and it is used in various devices and circuits. But we are using 20*4 LCD Display for this project. These modules are preferred over seven segments and other multi segment LEDs. It is basically available in electronic visible display, video display and flat panel display

## Pin Description of LCD Display


## PCB Designing


## References:

- BB-WI
https://beagleboard.org/support/bone101
- NodeMCU
https://lastminuteengineers.com/esp8266-nodemcu-arduino-tutorial/
- Xbee Module
https://components101.com/wireless/xbee-s2c-module-pinout-datasheet
- Buzzer
https://en.wikipedia.org/wiki/Buzzer

## References:

- Sensors:
https://components101.com/sensors/mq2-gas-sensor
https://wiki.seeedstudio.com/Grove-Gas_Sensor-MQ9/
https://www.fierceelectronics.com/sensors/what-a-temperature-sensor#:~:text=A%20temperature%20sensor%20is%20an,monitor%2C%20or%20signal%20temperature%20changes
- Opto-coupler
https://components101.com/ics/mct2e-phototransistor-optocoupler-ic
- PCB
https://en.wikipedia.org/wiki/Printed_circuit_board

## References:

- EasyEDA:
https://docs.easyeda.com/en/FAQ/Editor/index.html
https://www.youtube.com/watch?v=utBQqcuOt9U

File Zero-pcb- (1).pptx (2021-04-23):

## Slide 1

Smart Restaurant Food Ordering Menu using Beaglebone Black

Group Members :-
Amit Kumar (C0772515)
Ashok Kumar (C0762216)
Komalpreet Kaur (C0765526)
Ramandeep Kaur (C0772741)
Sagar Pasricha (C0765531)
Virender Singh (C0762540)

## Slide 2

Zero PCB Implementation of Receiver Side

Submitted by:- Virender Singh
( C0762540)

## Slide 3

Table of Contents

- Block Diagram of receiver side
- Components and protocols used
- Interfacing Diagram and Pin Diagram
- Final Schematics Diagram
- PCB and PCB Implementation
- Soldering
- Testing of PCB after Soldering

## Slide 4

Block Diagram of Receiver Side


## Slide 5

Components and Communication Protocol Used

- Components used at Receiver Side :-
- Beaglebone Black Wireless, Xbee Module, GSM Module, Arduino, Fan, Optocoupler, Temperature Sensor, CO Sensorr, LPG Gas and Smoke Sensor, LCD Display, Buzzer
- Communication Protocol Used :- UART

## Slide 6

Xbee S2C Module

- Xbee S2C module is a RF module rhat has been designed for the wireless communication or the data exchange and it works on the Zigbee mesh communication protocols.
- Basically this module provides the wireless connectivity to the end point devices in any Xbee mesh networks including devices from the other vendors.

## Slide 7

Interfacing of Xbee module with Beaglebone


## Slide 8

Interfacing of Xbee module with Beaglebone

- Connect pin1(Vcc) of Xbee to pin 4 (Vdd) of BBB wireless (P9 Header)
- Connect Pin 10(GND) of Xbee to pin 46 (GND) of BBB wireless (P9 Header)
- Connect Pin 2(Dout) of Xbee to pin 26 (UART1_Rx) of BBB wireless (P9) header
- Connect pin 3 (Din) of Xbee to pin 24 (UART_1Tx) of BBB wireless (P9 header)

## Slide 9

Interfacing of Xbee Module with Beaglebone


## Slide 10

Interfacing of Buzzer with Beaglebone Black Wireless

- Red wire(+ve) of buzzer connected to 23rd pin(GPIO_49) of P9 header of BB-WI.
- Black wire(Ground) of buzzer connected to 1st pin(DGND) of P9 header of BB-WI.


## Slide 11

MQ 2 Sensor

- MQ2 gas sensor is an electronic sensor used for sensing the concentration of gases in the air such as LPG, propane, methane, hydrogen, alcohol ,smoke and carbon monoxide.

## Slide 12

Interfacing of MQ 2 sensor with BB-WI

BB-WI(P9 Header) | MQ 2 Sensor
1(DGND) | GND
5(VDD 5V) | Vcc
33 (AIN4) | Vout

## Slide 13

Interfacing of MQ 2 sensor with BB-WI


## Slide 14

MQ 9 Sensor

- A gas sensor is a device which detects the presence or concentration of gases in the atmosphere. Based on the concentration of the gas the sensor produces a corresponding potential difference by changing the resistance of the material inside the sensor, which can be measured as output voltage. Based on this voltage value the type and concentration of the gas can be estimated.

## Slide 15

Interfacing of MQ 9 sensor with BB-WI

BB-WI(P9 Header) | MQ 9 Sensor
2 (DGND) | GND
6 (VDD 5V) | Vcc
36 (AIN5) | Vout

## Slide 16

Interfacing of MQ 9 sensor with BB-WI


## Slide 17

Temperature Sensor

- LM35 is an analog sensor (Temperature Sensor) which measures the temperature and linear output given in voltage form. ADC is required to convert analog output of temperature sensor to digital output. Since BBB has an on chip ADC, we can directly interface these two.

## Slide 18

Interfacing of Temperature sensor with BB-WI

Temperature Sensor | BB-WI (P9 Header)
GND | 1 (DGND)
Vcc | 5 (VDD 5V)
Vout | 38 (AIN3)

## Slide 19

Interfacing of Temperature sensor with BB-WI


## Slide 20

MCT2E Opto-coupler

- MCT2E is a phototransistor Optocoupler, as the name “phototransistor” suggests it has a transistor which is controlled based on light (photon).this IC basically has an IR (infrared) LED and a photo-transistor inside it. When the IR led is powered the light from it falls on the transistor and it conducts.A

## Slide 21

Interfacing of MCT2E Optocoupler with BB-WI

- Pin no 1 of MCT2E with gpio_67 pin 8 of P8 header of Beagle bone black wireless.
- Pin no 2 of MCT2E with DGND pin 1/2 of P9 header of Beagle bone black wireless.
- Pin no 4 of MCT2E with GND of Breadboard
- Pin no 5 of MCT2E with positive (red wire) of DC fan.

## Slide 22

LCD Display(20*4)

- LCD stands for Liquid Crystal Display. It is basically a screen that is used as an electric display module which has various range of applications. Most commonly used module is 16*2 LCD display and it is used in various devices and circuits. But we are using 20*4 LCD Display for this project. These modules are preferred over seven segments and other multi segment LEDs. It is basically available in electronic visible display, video display and flat panel display

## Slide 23

Pin Description of LCD Display


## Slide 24

The Basic PCB Design Process:

- It includes the design’s features, the functions the PCB must have and perform, interconnection with other circuits, placement, and the approximate final dimensions.
- The ideal PCB design flow begins when designers recognize a need that must be fulfilled, and it doesn’t end until testing verifies that the design can meet those needs.


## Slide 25

Gerber file:

- The Gerber file set is PCB jargon for the output files of the layout that are used by PCB manufacturers to create the PCB. A complete set of Gerber files includes output files generated from the board layout file:
- Silkscreen top and bottom
- Solder mask top and bottom
- All metal layers
- Component map (X-Y coordinates)
- Assembly drawing top and bottom
- Drill file
- Drill legend
- FAB outline (dimensions, special features)
- Netlist file

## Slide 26

PCB Design Top layer:


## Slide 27

PCB Design Bottom layer:


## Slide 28

What is PCB (Printed Circuit Board)

- PCB holds all the electrical components mechanically & connects them using conductive pads, tracks & other allied features.
- PCBs are primarily categorized based on the method of construction for example:
- Single-Sided PCBs, Double-Sided PCBs, Multilayer PCBs& more

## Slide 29

Types of PCB:

- Single-Sided PCBs
- Double-Sided PCBs
- Multilayer PCBs
- Rigid PCBs
- Flex PCBs
- Rigid-Flex PCBs
- Zero PCB(General purpose PCB)

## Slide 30

Zero PCBs

- Zero PCB is basically a general-purpose printed circuit board (PCB), also known as perfboard or DOT PCB.
- It is a thin rigid copper sheet with holes pre-drilled at standard intervals across a grid with 2.54mm (0.1-inch) spacing between holes.
- Each hole is encircled by a round or square copper pad so that component lead can be inserted into the hole and soldered around the pad without short-circuiting the nearby pads and other leads.
- For connecting the lead of component with another lead, we solder these together or join these using a suitable conducting wire.

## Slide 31

Soldering:

- For soldering we require:
- Soldering Lead
- Soldering Iron
- Flux along with a printed circuit board and layout diagram of the circuit.

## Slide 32

Soldering

Required Tools for Soldering

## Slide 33

Types of soldering

Different Methods of Soldering

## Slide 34

Soldering iron:

- Soldering iron is the required primary thing, which is used as a heat source for liquefying solder.
- 15W to 30W soldering guns are good for the majority of electronics or PCB (printed circuit board) jobs.
- The major difference between a gun and an iron is that iron seems like a pencil and comprises of a pin-point heat supply for the precise job, whereas a gun is like a gun in shape with a high wattage point excited by running electrical current simple through it.

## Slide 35

Soldering Process:

- Start with the small components to the taller components and connecting wires
- Place the element into the PCB, making sure it goes in the correct way around and twist the leads a little to secure the part.
- Make sure the soldering iron has warmed up and if required, use the moist sponge to clean the tip.
- Place the soldering iron on the component of the pad and feed the solder’s end onto the board
- Take away the solder and the soldering iron from the board and leave the terminal to cool for a few seconds.
- Using a couple of cutters neat the excess component terminal
- If you make a mistake while heat up the joint with the iron, place the solder tip of your solder extractor and push the button.

aa

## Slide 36

PCB Testing

- A continuity test tells us whether two things are electrically connected,if something is continuous, an electric current can flow freely from one end to the other.
- To begin, make sure no current is running through the circuit or component we want to test. Switch it off, unplug it from the wall, and remove any batteries.
- Plug the black probe into the COM port on your multimeter.
- Plug the red probe into the VΩmA port.
- Switch on the multimeter, and set the dial to continuity mode

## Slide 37

Testing Continuity:

- The multimeter tests continuity by sending a little current through one probe, and checking whether the other probe receives it.
- If the probes are connected—either by a continuous circuit, or by touching each other directly—the test current flows through. The screen displays a value of zero (or near zero), and the multimeter beeps.
- If the test current isn't detected, it means there's no continuity. The screen will display 1 or OL (open loop).
- To complete continuity test, place one probe at each end of the circuit or component we want to test.

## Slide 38

Testing Continuity:

- If multimeter doesn't have a dedicated continuity test mode, we can still perform a continuity test.
- Turn the dial to the lowest setting in the resistance mode.
- If the probes are connected—either by a continuous circuit, or by touching each other directly—the test current flows through. The screen displays a value of zero (or near zero—in this case, 0.8). Very low resistance is another way of saying that we have continuity.
- If no current is detected, it means there's no continuity. The screen will display 1 or OL (open loop).

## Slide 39

Testing Continuity


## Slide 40

Testing Voltage:

- Set the dial to DC voltage mode.
- Set the correct range for voltage.
- Place the red probe on the positive terminal, and the black probe on the negative terminal.
- With the range set correctly, we get an accurate reading.

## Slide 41

Refrences

- Types of PCB’s –retrieved from:
- https://www.crimpcircuits.com/blog/types-of-printed-circuit-boards/
- Zero PCB –retrieved from:
- https://www.electronicsforu.com/technology-trends/learn-electronics/veroboard-zero-pcb-difference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,%2Dinch)%20spacing%20between%20holes.
- PCB design process:
- https://www.electronicdesign.com/technologies/embedded-revolution/article/21798594/the-engineers-guide-to-highquality-pcb-design

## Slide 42

Refrences

Refrence for the Interfacing of the components on the receiver side retrieved from
https://github.com/komalkaurr/Group_3_Winter-2021/tree/main/PCB%20designing%20of%20reciever%20side
https://multimeterexpert.com/use-multimeter-test-solder-joint/

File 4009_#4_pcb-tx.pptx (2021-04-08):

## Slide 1

PCB designing of
Transmitter side

Sagar Pasricha (C0765531)

## What is pcb?

- A printed circuit board (PCB) mechanically supports and electrically connects electrical or electronic components using conductive tracks, pads and other features.
- Components are generally soldered onto the PCB to both electrically connect and mechanically fasten them to it.
- Electronic computer-aided design software is available to do much of the work of layout.
- PCBs can be single-sided (one copper layer), double-sided (two copper layers on both sides of one substrate layer), or multi-layer (outer and inner layers of copper, alternating with layers of substrate).

## Software available for pcb designing

- PROTEL (Altium Designer)
- PADS (PowerPCB)
- ORCAD
- Allegro
- Eagle
- Kicad
- EasyEda
- Fritzing
- and some more…

## Easy EDA

- Easy EDA is a web based EDA tool that enables the hardware engineers to design, simulate, share and discuss schematics, simulations and printed circuit boards. Features may include Bill of Materials, Gerber files and pick and place files and documentary outputs in PDF, PNG and SVG formats.
- Most of the things, such as libraries, projects, custom-made parts, packages and shared files are accessible via a simple drop down menu at the top left side of the software interface. This makes it easy for you to navigate through the software regardless of whether you are beginner or pro.

## Components and communication protocol used

Components used at Transmitter Side:
- Beaglebone Black Wireless
- Xbee Module
- Nextion Touch LCD
Communication Protocol Used:
- UART1

## Interfacing communication protocol: UART

- A universal asynchronous receiver-transmitter (UART) is a computer hardware device for asynchronous serial communication in which the data format and transmission speeds are configurable.
- It sends data bits one by one, from the least significant to the most significant, framed by start and stop bits so that precise timing is handled by the communication channel.


## Interfacing communication protocol: UART

- Beaglebone Black Wireless have 4.5 serial UARTs.
- For interfacing with touch screen display, we can use either of UART1, UART2, UART4.
- We cannot use UART3 for interfacing with touch screen display, because UART3 has only transmit pin.

## What is xbee?

- XBee S2C is a RF module designed for wireless communication or data exchange and it works on ZigBee mesh communication protocols.
- The module provides wireless connectivity to end-point devices in any ZigBee mesh networks including devices from other vendors.

## Pin diagram of xbee


## Pin description of xbee


## Pin description of xbee


## Pin description of xbee


## UART interfacing of Xbee


## Xbee Interfacing with BBB wireless

- Connect pin 1 (Vcc) of XBEE to pin4 (Vdd) of BBB wireless (P9 Header)
- Connect pin 10 (GND) of XBEE to Pin 46 (GND) of BBB wireless (P9 header )
- Connect pin 2 (Dout) of XBEE to pin26 (UART1_Rx) of BBB wireless (P9 Header)
- Connect pin 3 (Din) of XBEE to Pin 24 (UART1_Tx) of BBB wireless (P9 header )

## Xbee Interfacing with BBB wireless


## Nextion Touch LCD

- Nextion NX4827T043 4.3 Inch HMI Intelligent Smart UART Serial Touch TFT LCD Screen Module Display Panel.
- Nextion is a Seamless Human Machine Interface (HMI) solution that provides a control and visualization interface between a human and a process, machine, application or appliance. Nextion includes hardware part (a series of TFT boards) and software part (the Nextion Editor).
- The Nextion TFT board uses only one serial port to communicate. It lets you avoid the hassle of wiring..
- In Nextion editor, has mass components such as button, text, progress bar, slider, instrument panel etc. to enrich your interface design.

## Nextion Touch LCD


## Pin description of Nextion Touch LCD


## Features of Nextion Touch LCD

- 480 x 272 Resolution
- RGB 65K true to life colors
- TFT Screen with integrated 4-wire Resistive Touch Panel
- Easy 4 pin interface to any TTL Serial Host
- 16M Flash memory for User Application Code and Data
- On board micro-SD card for firmware upgrade
- Visual Area:95.04mm(L)×53.86mm(W)
- Adjustable Brightness:0~230 nit, the interval of adjustment is 1%
- 5V250mA power consumption

## Touch lcd Interfacing with BBB wireless

- Connect pin 1 (Vcc) of XBEE to pin4 (Vdd) 0f BBB wireless (P9 Header)
- Connect pin 4 (GND) of XBEE to Pin 46 (GND) of BBB wireless (P9 header )
- Connect pin 2 (Tx) of XBEE to pin26 (UART1_Rx) 0f BBB wireless (P9 Header)
- Connect pin 3 (Rx) of XBEE to Pin 24 (UART1_Tx) of BBB wireless (P9 header )

## Touch lcd Interfacing with BBB wireless


## Final schematic of transmitter side


## First method for pcb designing


Schematic with connections

## First method for pcb designing


PCB before
arrangement

## First method for pcb designing


PCB after
auto routing

## second method for pcb designing


Schematic without connections

## second method for pcb designing


PCB without connections

## second method for pcb designing


Top Layer

## Another method for pcb designing


Bottom Layer

## Pcb design top layer


## Pcb design bottom layer


## references

- EasyEDA tutorial. Retrieved from easyeda.com:
https (https://docs.easyeda.com/en/FAQ/Editor/index.html):// (https://docs.easyeda.com/en/FAQ/Editor/index.html)docs.easyeda.com/en/FAQ/Editor/index.html
- XBee S2C ZigBee (Wire Antenna). Retrieved from elediy.com:
https (https://elediy.com/products/xbee-s2c-zigbee-wire-antenna):// (https://elediy.com/products/xbee-s2c-zigbee-wire-antenna)elediy.com/products/xbee-s2c-zigbee-wire-antenna
- Zigbee Wireless Mesh Networking. Retrieved from www.digi.com
https (https://www.digi.com/solutions/by-technology/zigbee-wireless-standard)://www.digi.com/solutions/by-technology/zigbee-wireless-standard
- XBee pin-out description. Retrieved from components101.com
https://components101.com/wireless/xbee-s2c-module-pinout-datasheet#:~:text=XBee%20S2C%20is%20a%20RF,including%20devices%20from%20other%20vendors

## references

- What is PCB. Retrieved from wikipedia.org
https (https://en.wikipedia.org/wiki/Printed_circuit_board):// (https://en.wikipedia.org/wiki/Printed_circuit_board)en.wikipedia.org/wiki/Printed_circuit_board
- List of PCB design Software. Retrieved from seeedstudio.com
https://www.seeedstudio.com/blog/2017/03/13/pcb-design-software/
- Specifications of touch screen display. Retrieved from aliexpress.com
https (https://pl.aliexpress.com/item/32874330873.html)://pl.aliexpress.com/item/32874330873.html
- Interfacing of BB-WI with touch screen display. Retrieved from 14core.com
https://www.14core.com/working-with-nextion-hmi-gui-tft-touch-display/

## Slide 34

Any questions?

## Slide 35

Thank you

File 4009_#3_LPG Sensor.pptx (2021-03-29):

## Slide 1

Interfacing MQ7 sensor with
beaglebone

Sagar Pasricha (C0765531)

## Requirements for task

Beaglebone Black Wireless
MQ9 Sensor
Jumper wires
Laptop with Required Software
Node MCU

## What is sensor?

A sensor is a device, module, machine, or subsystem whose purpose is to detect events or changes in its environment and send the information to other electronics, frequently a computer processor. A sensor is always used with other electronics.
A good sensor obeys the following rules:
- It is sensitive to the measured property
- It is insensitive to any other property likely to be encountered in its application
- It does not influence the measured property.

## What is gas sensor?

- A gas sensor is a device which detects the presence or concentration of gases in the atmosphere.
- Based on the concentration of the gas the sensor produces a corresponding potential difference by changing the resistance of the material inside the sensor, which can be measured as output voltage.
- Based on this voltage value the type and concentration of the gas can be estimated.

## Applications of Gas Sensors

- Used in industries to monitor the concentration of the toxic gases.
- Used in households to detect an emergency incidents.
- Used at oil rig locations to monitor the concentration of the gases those are released.
- Used at hotels to avoid customers from smoking.
- Used in air quality check at offices.
- Used in air conditioners to monitor the CO2 levels.
- Used in detecting fire.
- Used to check concentration of gases in mines.
- Breath analyzer.

## different types of Gas Sensors

- Gas sensors are typically classified into various types based on the type of the sensing element it is built with.
- Below is the classification of the various types of gas sensors based on the sensing element that are generally used in various applications:
- metal oxide based gas sensor.
- Optical gas sensor.
- Electrochemical gas sensor.
- Capacitance-based gas sensor.
- Calorimetric gas sensor.
- Acoustic based gas sensor.

## Gas Sensors Construction

- Of all the above-listed types, the most commonly used gas sensor is the Metal oxide semiconductor based gas sensor.
- All Gas sensors will consist of a sensing element which comprises of the following parts.
- Gas sensing layer
- Heater Coil
- Electrode line
- Tubular ceramic
- Electrode

## Gas Sensors Construction


## Gas Sensors working

- The ability of a Gas sensor to detect gases depends on the chemiresister to conduct current.
- The most commonly used chemiresistor is Tin Dioxide (SnO2) which is an n-type semiconductor that has free electrons.
- Normally the atmosphere will contain more oxygen than combustible gases.
- The oxygen particles attract the free electrons present in SnO2 which pushes them to the surface of the SnO2.
- As there are no free electrons available output current will be zero.
- When the sensor is placed in the toxic or combustible gases environment, this reducing gas reacts with the adsorbed oxygen particles and breaks the chemical bond between oxygen and free electrons thus releasing the free electrons.

## Gas Sensors working

- As the free electrons are back to its initial position they can now conduct current, this conduction will be proportional the amount of free electrons available in SnO2, if the gas is highly toxic more free electrons will be available.


## list of Gas Sensors and what they sense


## Mq9 sensor

- MQ-9 gas sensor has high sensitity to Carbon Monoxide, Methane and LPG.
- The sensor can be used to detect different gases containing CO and combustible gases, it is low cost and suitable for different applications.
- Sensitive material of MQ-9 gas sensor is SnO2, which has a lower conductivity in clean air.
- It makes detection by cycling high and low temperature, and detects CO when low temperature (heated by 1.5V). The sensor’s conductivity is higher along with the gas concentration rising.
- When high temperature (heated by 5.0V), it detects Methane, Propane etc combustible gas and cleans the other gases adsorbed under low temperature.

## Mq9 sensor


## Mq9 sensor

Specification:
- Power supply needs: 5V
- Interface type: Analog
- Sensor Type: Semiconductor
- Concentration:
  - 10-1000ppm CO
  - 100-10000ppm combustible gas
- Good sensitivity to CO/Combustible gas
- High sensitivity to Methane, Propane and CO
- Long life and low cost

## MQ9 PIN CONFIGURATION


## MQ9 PIN CONFIGURATION

- There 4 leads are +5V, AOUT, DOUT, and GND.
- The +5V and GND leads establishes power for the alcohol sensor.
- The other 2 leads are Aout (analog output) and Dout (digital output).
- How the sensor works is the terminal Aout gives an analog voltage output in proportion to the amount of carbon monoxide the sensor detects. The more CO it detects, the greater the analog voltage it will output.
- Conversely, the less CO it detects, the less analog voltage it will output.
- If the analog voltage reaches a certain threshold, it will send the digital pin Dout high. Once this Dout pin goes high, the controller will detect this and will show a signal,

## CALCULATION OF MQ7 SENSOR DATA

- Each of the gas sensors outputs an analog value from 10 to 10000.
- To convert this value into voltage, use the following equation.
- Sensor Voltage = (dex * 5)/ 4095;
- CO sensor: PPM = 3.027*exp(sensor_output*1.0698);

## MQ9 SENSOR and beaglebone interfacing

Beaglebone | MQ9
PIN 40 (AIN 1) | AD0
VCC | VCC
GND | GND

## esp32 and beaglebone interfacing

Beaglebone | ESP32
PIN 24 (UART_Tx) | D1
PIN 24 (UART_Rx) | D2
GND | GND

## CONNECTIONs Image


## CODE for arduino ide

#include <ESP8266WiFi.h>

#include <BlynkSimpleEsp8266.h>

#include <SoftwareSerial.h>

SoftwareSerial mySerial(D1,D2); // RX, TX
String recieve; //global string declaration for recieveing data
// You should get Auth Token in the Blynk App.
// Go to the Project Settings (nut icon).
char auth[] = "sEBpNn9m6oZd5h5-zHmFwhApmzI_c1fj";

## CODE for arduino ide

// Your WiFi credentials.
// Set password to "" for open networks.
char ssid[] = "kalras";
char pass[] = "Moffatt27";
void setup()
{
// Debug console
Serial.begin(9600);
mySerial.begin(9600);
Blynk.begin(auth, ssid, pass);
}

## CODE for arduino ide

void loop()
{
recieve=mySerial.readString();
Serial.println(recieve);
if(recieve=="alert")
{
Blynk.notify("Attention ! Gas Leakage.");
// Blynk.email("2262010929@fido.ca" , "Alert from Sensor " ,"There is gas leakage in restaurant");
}
Blynk.run();
delay(2000); // delay of 60s
}

## CODE for beaglebone

#include <iostream> //provides basic input and output services for C++

#include <unistd.h> //provides access to the POSIX operating system API. #include <fstream> //performs input/output operations on the file

#include <math.h> // for mathematical operation

#include <stdio.h> //defines various functions for input output operations

#include <fcntl.h> //Used to define arguments for open ,close functions #include <unistd.h> //This is for misscelaneous functions declaration

#include <termios.h> // It contains the definitions used by terminal input output interfaces

#include <string.h>

#include <cstring>

## CODE for beaglebone

using namespace std;
int sensor_val() // generating a temerture function
{
int Smoke_sensor; // generating a local variable
fstream f; // generating a stream for file f.open("/sys/bus/iio/devices/iio:device0/in_voltage1_raw"); // config P9_40 AIN of BBBW
f>>Smoke_sensor; // giving file address to local variable
return (int)Smoke_sensor; //returning integer value to getTemp function
}

## CODE for beaglebone

int main()
{
float dex,sensor_output,b;
int file, count, pin_number;
file = open("/dev/ttyO1", O_RDWR); //this function open the file associated with Uart1
struct termios options; //declaration of a struct options
tcgetattr(file, &options); //This function get parameters associated with terminal and store them in termios
options.c_cflag = B9600 | CS8 | CREAD | CLOCAL;
options.c_iflag = IGNPAR | ICRNL;
tcflush(file, TCIFLUSH); //This function is used to clear input and output queue associated with terminal files
tcsetattr(file, TCSANOW, &options);

## CODE for beaglebone

char receive[] = "alert"; //recieve array declaration
while(1) {
dex= sensor_val();
sensor_output = (dex * 5)/ 4095; sensor_output=3.027*exp(sensor_output*1.0698);
cout<<"CO Sensor Reading : " << (int)sensor_output<<" ppm"<<endl; if((int)sensor_output > 620)
cout<<“Gas Leakage Alert” endl; {
write(file, receive, strlen(receive));
}
system("sleep 2"); // putting system to sleep
}
return 0;
}

## Sensor detection OUTPUT


## Notification on Blynk


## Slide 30

references

- What is sensor?. Retrieved from en.wikipedia.org
https://en.wikipedia.org/wiki/Sensor
- Introduction of gas sensor. Retrieved from components101.com
https://components101.com/articles/introduction-to-gas-sensors-types-working-and-applications
- Introduction of MQ9 sensor. Retrieved from dfrobot.com
https://wiki.dfrobot.com/Analog_Gas_Sensor_MQ9__SKU_SEN0134
- MQ9 Pin Configuration. Retrieved from learningaboutelectronics.com
http://www.learningaboutelectronics.com/Articles/MQ-7-carbon-monoxide-sensor-circuit-with-arduino.php
- Calculation for MQ9 Sensor Data. Retrieved from tutorialspoint.com
https://learn.sparkfun.com/tutorials/hazardous-gas-monitor/calculate-gas-sensor-ppm

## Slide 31

Any questions?

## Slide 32

Thank you

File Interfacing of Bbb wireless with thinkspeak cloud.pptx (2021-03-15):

## Interfacing of Bbb wireless with thinkspeak cloud

abstract image

- 9.24.XX

- Submitted by
- Amit kumar

## What is iot?

table with various people working on their laptops

- The Internet of things (IoT) describes the network of physical objects—“things”—that are embedded with sensors, software, and other technologies for the purpose of connecting and exchanging data with other devices and systems over the Internet.

## Key Benefits of IoT Platforms Software

group of people at a conference table

- Design and execute complex IoT projects using internal resources
- Establish communication protocols for connected hardware
- Determine which data will be collected by sensors and which actions will be carried out by IoT devices
- Integrate business systems and software with connected assets to allow the smooth, continuous flow of data

## List of IOT services provider

- ThingSpeak - By Mathworks,Inc
- Amazon web services - Amazon
- Twilio - Twilio
- Upswift - Upswift, Inc
- ARTIK - Samsung Electronics co.
- JASPER - Jasper Technologies, Inc.
- ThingWorx - PTC, Inc
- Etc..

## What is ThinGSpeak?

- ThingSpeak is an open-source Internet of Things (IoT) application and API to store and retrieve data from things using the HTTP and MQTT protocol over the Internet or via a Local Area Network.
- ThingSpeak has integrated support from the numerical computing software MATLAB from MathWorks,[4] allowing ThingSpeak users to analyze and visualize uploaded data using Matlab without requiring the purchase of a Matlab license from Mathworks.

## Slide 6


## WHat is Http?

- The Hypertext Transfer Protocol (HTTP) is an application layer protocol for distributed, collaborative, hypermedia information systems. HTTP is the foundation of data communication for the World Wide Web, where hypertext documents include hyperlinks to other resources that the user can easily access, for example by a mouse click or by tapping the screen in a web browser.
- HTTP functions as a request–response protocol in the client–server computing model. A web browser, for example, may be the client and an application running on a computer hosting a website may be the server. The client submits an HTTP request message to the server. The server, which provides resources such as HTML files and other content, or performs other functions on behalf of the client, returns a response message to the client. The response contains completion status information about the request and may also contain requested content in its message body

## What is Mqtt?

- MQTT (Message Queuing Telemetry Transport) is an open OASIS and ISO standard (ISO/IEC 20922) lightweight, publish-subscribe network protocol that transports messages between devices. The protocol usually runs over TCP/IP; however, any network protocol that provides ordered, lossless, bi-directional connections can support MQTT. It is designed for connections with remote locations where a "small code footprint" is required or the network bandwidth is limited.
- The MQTT protocol defines two types of network entities: a message broker and a number of clients. An MQTT broker is a server that receives all messages from the clients and then routes the messages to the appropriate destination clients. An MQTT client is any device (from a micro controller up to a fully-fledged server) that runs an MQTT library and connects to an MQTT broker over a network

## Components of Channel on Thingspeak

- Number of Fields (8 ) on any channel on free version of thingSpeak.
- Longitude and Latitude
- Github link
- Video URL
- External Site

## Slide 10


## Features of Channel

MATLAB Visualition and Analysis
Private View and Public View
Export and Import Data
API keys (read and write API keys)

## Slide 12


## Uses of api Keys

- Types of API keys
- Read API key
- Write API key
- User API key
- Read and Write API keys are only used for reading and writing data in our channel.
- User API key is used for our account purpose .

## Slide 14


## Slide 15


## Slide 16


## Apps features of thingspeak

Computer script on a screen

- MATLAB analysis
- MATLAB visualization
- React
- Talkback
- ThingTweet
- TimeControl
- ThingHTTP

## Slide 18


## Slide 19


## BBB wireless Wifi Module

- The BeagleBone Black Wireless (BBBW) uses the same wireless chip as the BeagleBone Green Wireless (BBGW), which is the WL18MODGB TI module.
- BBBW does not have a built-in antenna therefore solely relies on the provided external antennas.
- This revision has also removed the Ethernet port and as such users will have to rely on the WiFi for Internet connectivity.


## Setup wifi fo BBB wireless

- ssh debian@192.168.7.2
- sudo connmanctl
- connmanctl> enable wifi
- connmanctl> Services
- connmanctl> agent on
- connect wifi_xxxxxxxx_managed_psk
- quit

## Advantages of using Thingspeak

- ThingSpeak allows you to aggregate, visualize and analyze live data streams in the cloud. Some of the key capabilities of ThingSpeak include the ability to:
- Easily configure devices to send data to ThingSpeak using popular IoT protocols.
- Visualize your sensor data in real-time.
- Aggregate data on-demand from third-party sources.
- Use the power of MATLAB to make sense of your IoT data.
- Run your IoT analytics automatically based on schedules or events.
- Prototype and build IoT systems without setting up servers or developing web software.
- Automatically act on your data and communicate using third-party services like Twilio® or Twitter®.

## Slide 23


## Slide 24


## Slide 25


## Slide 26


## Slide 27


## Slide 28


## Limitation of thinkspeak!

- Free users are limited to 10 million messages (3+ years at minimum update interval)
- Paid users are limited to 100 million messages per unit (3+ years at minimum update interval)
- If storage is exceeded, your channels may no longer be able to receive data.
- Long term archiving of data for paid customers only.
- We can only upload integer values on ThingSpeak.

## References

- Http information
https://en.wikipedia.org/wiki/Hypertext_Transfer_Protocol
- MQTT information
https://en.wikipedia.org/wiki/MQTT
- ThingSpeak information
https://thingspeak.com/pages/learn_more

## References

- Coding for ThingSpeak
http://exploringbeaglebone.com/chapter11/
- link for ThingSpeak channel
https://thingspeak.com/channels

## Questions? Thank YOU


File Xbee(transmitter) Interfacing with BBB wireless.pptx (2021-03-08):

## Xbee(transmitter) Interfacing with BBB wireless

Submitted by
Ashok Kumar Saini(c0762216)

## What is Xbee?

- XBee S2C is a RF module designed for wireless communication or data exchange and it works on ZigBee mesh communication protocols that sit on top of IEEE 802.15. 4 PHY.
- The module provides wireless connectivity to end-point devices in any ZigBee mesh networks including devices from other vendors.

## Pin Diagram of Xbee


z

## Pin Configuration of Xbee

Pin | Name | Description
1 | VCC | Power supply
2 | DOUT/DIO13 | UART data out pin (TXD)/GPIO
3 | DIN/CONFIG / DIO14 | UART data in pin (RXD)/ GPIO
4 | DIO12/SPI_MISO | GPIO/ Master Input-Slave Output pin of SPI interface
5 | RESET | Module Reset pin
6 | RSS PWM /DIO10 | RX Signal Strength Indicator pin / GPIO
7 | PWM1/DIO11 | Pulse Width Modulator/GPIO

## Pin Configuration of Xbee

Pin | Name | Discription
8 | RESERVED | Do not connect
9 | DTR/SLEEP_RQ/ DIO8 | Pin Sleep Control line /GPIO
10 | GND | Ground
11 | DIO4/ SPI_MOSI | GPIO/Master Output-Slave Input pin of SPI interface
12 | CTS/DIO7 | Clear-to-send flow control/GPIO
13 | ON_SLEEP/DIO9 | Device status indicator/GPIO
14 | VREF | Voltage Reference for ADC

## Pin Configuration of Xbee

Pin | Name | Discription
15 | ASC/DIO5 | Associate Indicator/GPIO
16 | RTS/DIO6 | Request to send flow control/ GPIO
17 | AD3/DIO3/SPI_SSEL | Analog input/GPIO/SPI slave select
18 | AD2 /DIO2/SPI_CLK | Analog input/GPIO/SPI clock
19 | AD1/DIO1/SPI_ATTN | Analog input/GPIO/SPI attention
20 | AD0/DIO0/C | Analog input/GPIO/ Commissioning button

## Features and Electrical Characteristic of Xbee

- Transmission Frequency: 2.4GHz to 2.5GHz
- Number of Channels: 16 Direct Sequence Channels
- Featured with UART (250 Kb/s maximum) and SPI (5 Mb/s maximum) interface
- Featured with software adjustable transmitting power
- Indoor/Urban Range: 200ft
- Outdoor RF line-of-sight Range: up to 4000ft
- Transmit Power Output: 6.3mW (8dBm) in Boost mode,2mW (3dBm) in Normal mode

## Features and Electrical Characteristic of Xbee

- Receiver Sensitivity: -102dBm in Boost mode, -100dBm in Normal mode
- Supply Voltage Range: +2.1V to +3.6V
- Operating Current: 33mA (at3.3V, for Normal mode) , 45mA (at 3.3V,for Boost mode)
- Idle Current: 9mA
- Maximum output current on all pins together: 40mA
- Power-down Current: <1uA @25C
- ESD protection: 3000V
- Operating Temperature: -40ºC to 85° C

## Need of Xbee module !

- As our project has two isolated part (transmitter/receiver ). We need to send Data from one part to other.
- Xbee provides sufficient data rate (250Kbps).
- Simplicity in configuration and interfacing with microcontrollers.
- A single XBee module does not have much use unless you already have a ZigBee mesh network up and running. So if there is no mesh network working you need at least two modules for establishing wireless communication.

## UART interfacing of Xbee


## UART interfacing of Xbee


## Software used for Xbee- XCTU

- XCTU is a free, multi-platform application compatible with Windows, MacOS and Linux
- Graphical Network View for simple wireless network configuration and architecture
- API Frame Builder is a simple development tool for quickly building XBee API frames
- Firmware Release Notes Viewer allows users to explore and read firmware release notes

## XCTU software


## Configuring Xbee

- PAN ID- Assign same for Both Xbees
- MAC address (16 bits)
Xbee1 -> 0013A20041D157C6
Xbee2 -> 0013A20041D18631
1. High
2. Low
- Node Identifier
- CE Coordinator Enable

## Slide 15


## Xbee configuration as transmitter


## Xbee Configuration as Receiver


## Pin Diagram of BBB wireless


## Interfacing with BBB wireless

- Connect pin 1 of Xbee to pin4 0f BBB wireless (P9 Header)
- Connect pin 10 of Xbee to Pin 46 of BBB wireless (P9 header )
- Connect pin 2 of Xbee to pin26 0f BBB wireless (P9 Header)
- Connect pin 3 of Xbee to Pin 24 of BBB wireless (P9 header )

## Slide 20


## Interfacing with Arduino

- Connect pin 1 of Xbee to 3.3V 0f Arduino uno wireless
- Connect pin 10 of Xbee to GND Arduino uno
- Connect pin 2 of Xbee to Tx of Arduino uno
- Connect pin 3 of Xbee to Rx of Arduino uno

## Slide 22


## UART interfacing of Xbee using C

- Add kernel Libraries
- Save USB locations of Devices
- Give Commands to Communicate with other Xbee

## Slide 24


## UART interfacing of Xbee using python

- import Adafruit_BBIO.UART as uart
- uart.setup('UART1')
- import serial
- xbee=serial.Serial(port="/dev/ttyO1", 9600, timeout=1)
- while(1):
print(xbee.readline())
- xbee.write('From Beaglebone')

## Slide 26


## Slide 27


## Reference

- Xbee configuration
https://components101.com/wireless/xbee-s2c-module-pinout-datasheet#:~:text=XBee%20S2C%20is%20a%20RF,including%20devices%20from%20other%20vendors.
- XCTU software
https://www.digi.com/products/embedded-systems/digi-xbee/digi-xbee-tools/xctu#productsupport-utilities

## Reference

- Interfacing of (https://stackoverflow.com/questions/tagged/beagleboneblack?sort=votes&page=4)xbee (https://stackoverflow.com/questions/tagged/beagleboneblack?sort=votes&page=4)
- https://stackoverflow.com/questions/tagged/beagleboneblack?sort=votes&page=4
- https://medium.com/@ing.david.mata/in-this-tutorial-i-am-going-to-show-you-how-you-can-send-data-wirelessly-between-an-arduino-to-a-cb18cac1c984

## Questions? Thanks

z

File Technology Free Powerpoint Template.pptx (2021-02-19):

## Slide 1

ALL ABOUT
HARDWARE COMPONENTS


SUBMITTED TO:
PROF. MIKE ALESHAMS
SUBMITTED BY:
ASHOK KUMAR SAINI

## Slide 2

CONTENTS

- List of Hardware Components
- Bills and status of the orders
- Specifications
- Reference

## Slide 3

- 2 Beaglebone
- Arduino UNO
- GSM module (SIM 900)
- Xbee S2C RF module (Rx and Tx)
- 20*4 LCD Module
- 4.3" cape LCD touch screen (Nextion)

Hardware components used in my project

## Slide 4

- Breadboard/Zero PCB
- 2 SD cards (32GB each)
- Jumper wires
- Power supply (Adapter)
- Soldering Equipment (soldering iron, soldering wire)
- Carbon Monoxide detection sensor

Hardware components used in my project

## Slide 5

- Temperature Sensor (LM 35)
- Smoke and LPG gas sensor (MQ-2)
- Mct2e optocoupler
- Buzzer
- Wire cutter
- Wire stripper

Hardware components used in my project

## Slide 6

- 12v DC Fan
- Power supply

Hardware components used in my project

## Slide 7

Beaglebone black

Beaglebone black

This Photo (https://blog.csdn.net/lu_embedded/article/details/86358225) by Unknown Author is licensed under CC BY-SA (https://creativecommons.org/licenses/by-sa/3.0/)

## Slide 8

Specifications:

- 512MB DDR3 RAM
- 4GB 8-bit eMMC on-board flash storage
- 3D graphics accelerator
- NEON floating-point accelerator
- 2x PRU 32-bit microcontrollers

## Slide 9

- USB client for power & communications
- USB host
- Ethernet
- HDMI
- 2x 46 pin headers

Connectivity

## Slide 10

- Basically it is central MCU which is master controller, used to control all peripherals(sensors, XBee module, input and output screens).
- Link for purchase:
https://www.digikey.ca/en/products/detail/ghi-electronics-llc/BBBWL-SC-562/6211000

Some other info of beaglebone:

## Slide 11

Arduino UNO


This Photo (http://www.jeffreykopcak.com/2014/03/17/dongle-bits-raspberry-pi-and-arduino/) by Unknown Author is licensed under CC BY-NC (https://creativecommons.org/licenses/by-nc/3.0/)

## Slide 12

- ATmega328 microcontroller
- Input voltage - 7-12V
- 14 Digital I/O Pins (6 PWM outputs)
- 6 Analog Inputs
- 32k Flash Memory
- 16Mhz Clock Speed

Features:

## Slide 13

- Link for purchasing Arduino UNO
https://www.amazon.ca/Arduino-A000073-Uno-REV3-SMD/dp/B00PUOVSYS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

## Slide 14


Gsm module

This Photo (https://hetpro-store.com/TUTORIALES/sim900-gsm-shieldarduino/) by Unknown Author is licensed under CC BY (https://creativecommons.org/licenses/by/3.0/)

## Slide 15

Some features:

- Embedded TCP/UDP stack - allows you to upload data to a web server. RTC supported. Selectable serial port. Speaker and Headphone jacks. Low power consumption - 1.5mA(sleep mode).
- The TTL serial port is compatible with 3.3 and 5V microcontrollers.
- This module is powered by: 5V-26V, 5V 2A power supply is recommended. After plugging in the motherboard, the power supply must be able to supply 2A.
- Standard Commands: GSM 07.07 & 07.05 | Enhanced Commands: SIMCOM AT Commands. Short Message Service - so that you can send small amounts of data over the network (ASCII or raw hexadecimal).

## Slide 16

Link for purchasing:
https://www.amazon.ca/Development-Board-Module-SIM900-Antenna/dp/B07XY79G56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

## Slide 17


Xbee S2C RF module (Rx and Tx)

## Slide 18

- Transmission Frequency: 2.4GHz to 2.5GHz
- Number of Channels: 16 Direct Sequence Channels
- Featured with UART (250 Kb/s maximum) and SPI (5 Mb/s maximum) interface
- Featured with software adjustable transmitting power
- Indoor/Urban Range: 200ft

Features and Electrical Characteristics

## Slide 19

- Transmit Power Output: 6.3mW (8dBm) in Boost mode,2mW (3dBm) in Normal mode
- RF Data Rate: 250,000 bps
- Receiver Sensitivity: -102dBm in Boost mode, -100dBm in Normal mode
- Supply Voltage Range: +2.1V to +3.6V

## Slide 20

- Link for purchase:
https://www.digikey.ca/en/products/detail/digi/XB24CAWIT-001/6010100

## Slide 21

20*4 LCD Module


This Photo (http://www.electronics-lab.com/project/lm35-lcd-thermometer-using-pic16f676/) by Unknown Author is licensed under CC BY-SA (https://creativecommons.org/licenses/by-sa/3.0/)

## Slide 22

- With this shield, you can display whatever you want by programming the for Arduino board.
- (Easy to Use) Less I/O ports are occupied, only four - VCC, GND, SDA (serial data line), SCL (serial clock line). Address of the module: 0x27.

Features

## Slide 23

- (Support IIC Interface) It only takes two I/O port thus saving more for other usages.
- (Widely Applications) LCD display module based on the popular HD44780 controller, works great with for Arduino / Uno R3 / Mega2560 board and other micro-controllers.

Features

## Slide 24

- Link for purchase
https://www.amazon.ca/WayinTop-Display-Interface-Adapter-Arduino/dp/B07TXGD3WS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

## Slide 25


4.3" cape LCD touch screen (Nextion)

This Photo (http://select.marutsu.co.jp/list/detail.php?id=236) by Unknown Author is licensed under CC BY-ND (https://creativecommons.org/licenses/by-nd/3.0/)

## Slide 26

- NX4827T043 is nextion 4.3 basic screen: 4.3 inch TFT, 480x272 resistive touch display, 16M flash, 2K Byte RAM, 65k colors.
- Uploading TFT file via sd card is faster than 4pin serial port, but pls check card format is FAT32 and no more than 32GB.

Features

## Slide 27

- Link for purchase
https://www.amazon.ca/Nextion-NX4827T043-Intelligent-Display-Module/dp/B07B9XTSWH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

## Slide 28


Zero PCB

This Photo (https://avdweb.nl/tech-tips/smd-breadboard) by Unknown Author is licensed under CC BY-SA-NC (https://creativecommons.org/licenses/by-nc-sa/3.0/)

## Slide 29

- It is basically a general-purpose printed circuit board (PCB), also known as perfboard or DOT PCB. It is a thin rigid copper sheet with holes pre-drilled at standard intervals across a grid with 2.54mm (0.1-inch) spacing between holes. Each hole is encircled by a round or square copper pad so that component lead can be inserted into the hole and soldered around the pad without short-circuiting the nearby pads and other leads. For connecting the lead of component with another lead, solder these together or join these using a suitable conducting wire.
- Link for purchase
https://www.amazon.ca/YUNGUI-Solder-able-Breadboard-Electronic-Experiment/dp/B07TTD5V2W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

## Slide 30

- Rows and columns are labeled (a-z & 1-48) for easy operation.Though hole PCB boards with 1440( 48*30) tie points.
- The material is all FR4 full glass fiber plate, which can effectively prevent the pad from falling off.

Features

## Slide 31


SD cards

This Photo (http://www.melissasbargains.com/transcend-32-gb-microsdhc-flash-memory-card-for-23-99-60-off-today-only/) by Unknown Author is licensed under CC BY-NC-ND (https://creativecommons.org/licenses/by-nc-nd/3.0/)

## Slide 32

- Main function is to flash latest debian image to BBB.
- Transfer read speeds of up to 98MB/s.
- Shockproof, temperature-proof, waterproof, and X-ray-proof

Features

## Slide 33

Link for purchase: (https://www.amazon.ca/Sandisk-SDSQUAR-032G-GN6MA-Ultra-Micro-Adapter/dp/B073JWXGNT?hvadid=208333453601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)
https://www.amazon.ca/Sandisk-SDSQUAR-032G-GN6MA-Ultra-Micro-Adapter/dp/B073JWXGNT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

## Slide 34

Jumper wires


This Photo (http://electronics.stackexchange.com/questions/82830/how-to-secure-jumper-wire-connections) by Unknown Author is licensed under CC BY-SA (https://creativecommons.org/licenses/by-sa/3.0/)

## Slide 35

- Link for purchase:
https://www.amazon.ca/Elegoo-120pcs-Multicolored-Breadboard-arduino/dp/B01EV70C78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
- For connecting components through breadboard.

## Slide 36

- Each cable length: about 20 cm /8-inch.
- The cables can be separated to form an assembly containing the number of wires you require for your connection and to support non-standard odd-spaced headers.

Features

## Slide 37


Soldering Equipment

This Photo (https://technofaq.org/posts/2016/05/four-things-to-learn-for-any-electronics-hobbyist/) by Unknown Author is licensed under CC BY-SA-NC (https://creativecommons.org/licenses/by-nc-sa/3.0/)

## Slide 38

- 30W adjustable temperature Soldering iron (Model XY258) - with a temperature control on the side and indicator LED so you can go from standard to lead-free to silver solder.
- Digital Multimeter - Model 9205B+ is a good-all-around basic multimeter. Has a continuity tester, DC/AC voltage and current, resistance, transistor and diode/LED test. Runs on a 9V battery.
- Wire strippers- We've upgraded our basic 'adjustable' wire strippers to these multi-sized wire strippers. They include: 22-30 AWG strippers, wire cutters, 'plier' tips, and a wire loop.
- Solder sucker - Strangely enough, that's the technical term for this desoldering vacuum tool.
- Micro needle-nose pliers - for bending, forming, holding, squeezing and plying all of those little components.
- Diagonal cutters - the best diagonal cutters, these are comfortable to use and have strong nippers for perfect trimming of wires and leads.
- Solderless breadboard.

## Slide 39

- Link for purchase:
https://elmwoodelectronics.ca/products/ladyadas-electronics-toolkit

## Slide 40


12v DC Fan

This Photo (https://commons.wikimedia.org/wiki/File:11718_-_DC_Brushless_Fan_-_80x80x15mm_(12V).jpg) by Unknown Author is licensed under CC BY-SA (https://creativecommons.org/licenses/by-sa/3.0/)

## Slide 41

- Operating Voltage Range：5.5V to 13.8V.
- Rated Voltage: DC 12V; Rated Current: 0.18mp; Rated Speed: 2800RPM; Air flow: 32.8CFM; Noise: 28dBA
- Bearing Type: Sleeve Bearing ; Life: working up to 35000h at 25 degrees.

Features

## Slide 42

- Link for purchase
https://www.amazon.ca/GDSTIME-80mm-15mm-Brushless-Cooling/dp/B081YST8ZL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

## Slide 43


Opto-coupler

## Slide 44

- This device allows to transmit an electrical signal between two isolated circuits .
- Link for purchase
https://www.digikey.ca/en/products/detail/on-semiconductor/MCT2EM/400424

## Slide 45


Carbon Monoxide detection sensor

This Photo (http://www.cosino.it/product/mq-7-gas-sensor?add-to-cart=1325) by Unknown Author is licensed under CC BY-SA (https://creativecommons.org/licenses/by-sa/3.0/)

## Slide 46

- For home or factory gas leakage monitoring devices, suitable for carbon monoxide and other combustible gases.
- Specifications: Product Model: MQ-9 - ProductType: Se-miconduct gas sensitive element , Gas Detected: Carbon monoxide, Combustible gas , Detectable Concentration: 10-1000 ppmCO, 100-10000 PPM gas.

Features

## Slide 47

- Link for purchase
https://www.amazon.com/MQ-Carbon-Monoxide-Combustible-Sensor/dp/B01N2MW3X5

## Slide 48


Temperature Sensor

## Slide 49

- It is used to measure if temperature is above any given range or not.
- Link for purchase:
https://www.digikey.ca/en/products/detail/texas-instruments/LM35DZ-NOPB/32489

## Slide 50

- Minimum and Maximum Input Voltage is 35V and -2V respectively. Typically 5V.
- Can measure temperature ranging from -55°C to 150°C.
- ±0.5°C Accuracy Drain current is less than 60uA.

Features

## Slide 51


Smoke sensor

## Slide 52

- It can detect flammable gas in a range of 300 - 10000ppm.
- It's most common use is domestic gas leakage alarms and detectors with a high sensitivity to propane and smoke.
- Link
https://www.sparkfun.com/products/17049

Features

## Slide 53


buzzer

This Photo (https://digistump.com/wiki/oak/tutorials/buzzer) by Unknown Author is licensed under CC BY-SA-NC (https://creativecommons.org/licenses/by-nc-sa/3.0/)

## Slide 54

- Magnetic 5V Panel Mount, Flange PC Pins.
- It is used to alert kitchen staff about new order.
- Link
https://www.digikey.ca/en/products/detail/tdk-corporation/SD1614T5-B5ME/8017772

Features

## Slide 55

Power supply

1. Power adapter for beaglebone:
5v and 2 amp
2) Battery for fan:
9v

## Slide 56

References:
1. Beaglebone black:
https://beagleboard.org/black
2) Arduino UNO:
https://www.amazon.ca/Arduino-A000073-Uno-REV3-SMD/dp/B00PUOVSYS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
3) Gsm module:
https://www.amazon.ca/Development-Board-Module-SIM900-Antenna/dp/B07XY79G56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

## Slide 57

References:
4) Xbee S2C RF module (Rx and Tx):
https://www.digikey.ca/en/products/detail/digi/XB24CAWIT-001/6010100
5) 20*4 LCD Module:
https://www.amazon.ca/WayinTop-Display-Interface-Adapter-Arduino/dp/B07TXGD3WS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
6) 4.3" cape LCD touch screen (Nextion):
https://www.amazon.ca/Nextion-NX4827T043-Intelligent-Display-Module/dp/B07B9XTSWH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

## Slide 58

References:
7) Zero PCB:
https://www.amazon.ca/YUNGUI-Solder-able-Breadboard-Electronic-Experiment/dp/B07TTD5V2W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
8) Sd cards:
https://www.amazon.ca/Sandisk-SDSQUAR-032G-GN6MA-Ultra-Micro-Adapter/dp/B073JWXGNT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

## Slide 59

References:
8) Jumper wires:
https://www.amazon.ca/Elegoo-120pcs-Multicolored-Breadboard-arduino/dp/B01EV70C78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
8) Solder kit:
https://elmwoodelectronics.ca/products/ladyadas-electronics-toolkit
9) fan:
https://www.amazon.ca/GDSTIME-80mm-15mm-Brushless-Cooling/dp/B081YST8ZL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

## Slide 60

References:
10) optocoupler:
https://www.digikey.ca/en/products/detail/on-semiconductor/MCT2EM/400424
11) Smoke sensor:
https://www.sparkfun.com/products/17049
12) Temperature sensor:
https://www.digikey.ca/en/products/detail/texas-instruments/LM35DZ-NOPB/32489
13) buzzer:
https://www.digikey.ca/en/products/detail/tdk-corporation/SD1614T5-B5ME/8017772

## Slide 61


Invoice:

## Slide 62

Invoice:


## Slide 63

Invoice:


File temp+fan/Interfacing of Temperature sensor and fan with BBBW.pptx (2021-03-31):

## Interfacing of Temperature sensor and fan with BBBW

Submitted by
Ashok Kumar Saini

## Objectives

- Introduction
- Requirement
- LM35 Temperature Sensor
- Optocoupler Working
- Coding
- Output
- Reference

## Introduction

- Our Project is about Smart Restaurant Ordering Menu
- Use of temp sensor to sense temperature (kitchen)
- If Temperature is above a threshold then Switch ON the Fan
- Fan is Isolated from BBBW through Octocoupler

## Requirement

- LM35 Temperature Sensor
- MCT2E Optocoupler
- Jumper Wires
- DC fan
- Beagle Bone Black Wireless
- A PC/Laptop

## Temperature Sensor

- LM35 is a precession Integrated circuit Temperature sensor, whose output voltage varies, based on the temperature around it. It is a small and cheap IC which can be used to measure temperature anywhere between -55°C to 150°C.
- It can easily be interfaced with any Microcontroller that has ADC function or any development platform like Arduino.

## Temperature Sensor

- Power the IC by applying a regulated voltage like +5V (VS) to the input pin and connected the ground pin to the ground of the circuit.
- If the temperature is 0°C, then the output voltage will also be 0V. There will be rise of 0.01V (10mV) for every degree Celsius rise in temperature.


## Features of Temperature Sensor

- LM35 Regulator Features:
- Minimum and Maximum Input Voltage is 35V and -2V respectively. Typically 5V.
- Can measure temperature ranging from -55°C to 150°C
- Output voltage is directly proportional (Linear) to temperature (i.e.) there will be a rise of 10mV (0.01V) for every 1°C rise in temperature.
- ±0.5°C Accuracy
- Drain current is less than 60uA
- Low cost temperature sensor
- Small and hence suitable for remote applications

## Pin Configuration

Pin Number | Pin Name | Description
1 | Vcc | Input voltage is +5V for typical applications
2 | Analog Out | There will be increase in 10mV for raise of every 1°C. Can range from -1V(-55°C) to 6V(150°C)
3 | Ground | Connected to ground of circuit

## Calculation of Temperature

- Step size of LM 35 is 10 mV means when 1 degree temperature changes, output voltage of sensor increases by 10 mV.
- Step size of ADC is 0.44 mV that’s why we need to divide it by 22.75 to get the correct temperature in Celsius.
- Factor value = 10 mV / 0.44 mV = 22.75 mV
- Dout = (Vin * 4096) / 1800
- Celsius = (Dout)/22.75

## Connecting LM35 to BBBW


Pin
Pin 1 of (vcc) of LM35 to pin 4 of P9 header of BBBW.
Pin
Pin 2 of (analog Output) of LM35 to pin 40 of P9 header of BBBW.
Pin
Pin 3 of (GND) of Lm35 to pin 45 or 46 of P9 header of BBBW.

## MCT2E Optocoupler

- MCT2E is a phototransistor Optocoupler, as the name “phototransistor” suggests it has a transistor which is controlled based on light (photon).
- this IC basically has an IR (infrared) LED and a photo-transistor inside it. When the IR led is powered the light from it falls on the transistor and it conducts.

## MCT2E pin Configuration

Pin Number | Pin Name | Description
1 | Anode (A) | Anode pin of the IR LED. Connected to logic input
2 | Cathode (C) | Cathode pin of the IR LED
3 | NC | Cannot be used
4 | Emitter (E) | Emitter pin of the Transistor. Connected to isolated ground.
5 | Collector (C) | Collector pin of the Transistor. This is the logic output pin
6 | Base (B) | Base pin of the Transistor. It is normally not used for transistor mode, but will be used in diode mode

## MCT2E Optocoupler

- This IC is used to provide electrical isolation between two circuits, one part of the circuit is connected to the IR LED and the other to Photo-transistor.


## MCT2E Optocoupler

- The digital signal given to the IR LED will be reflected on the transistor but there will be no hard electrical connection between the two.


z

## Working of MCT2E

- when the Logic input is low the IR LED will not conduct and hence the transistor will also be in off state.
- The Logic input is made high, this high voltage should be a minimum of 1.25V (Diode Forward voltage) the IR LED conducts and so the photo-transistor is also turned on. This will short the collector and emitter and hence the Logic Output voltage will become zero. This way the logic input will be reflected at the logic output and still provides and isolation between the two.

## MCT2E Optocoupler specification

- Input Diode Forward Voltage: 1.25V
- Collector-Emitter Voltage: 30V
- On-State Collector Current: 5mA
- Transistor HFE: 300
- Rise Time: 5us
- Fall Time: 5us
- Available as 6-pin PDIP with and without M-suffix

## Connection with BBBW

- Pin no 1 of MCT2E with gpio_67 pin 8 of P8 header of Beagle bone black wireless.
- Pin no 2 of MCT2E with DGND pin 1/2 of P9 header of Beagle bone black wireless.
- Pin no 4 of MCT2E with GND of Breadboard
- Pin no 5 of MCT2E with positive (red wire) of DC fan.

## DC fan

- Fan Size: 120x120x25mm
- RPM: 3000 +/- 10%
- Rated Current: 0.36 Amp Running / 0.6 Amp Startup
- Airflow: 105 CFM
- Noise: 42 dB
- Rated Voltage: 12 V DC
- Bearing Type: Ball Bearing


## Pin configuration for BBBW


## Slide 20


## Code

- include<iostream> //This header file contains all the functions of program like cout, cin etc.
- #include<cstring> //This header file declares a set of functions to work with C style string.
- #include<unistd.h> // This header file is for miscellaneous functions declaration.
- #include "buzzer.h" //It contains buzzer function.
- #define LOW 0
- #define HIGH 1
- using namespace std;

## Code

- int pin_number=67; //This is a GPIO_67 of Beaglebone Black Wireless
- int getTemp() // generating a temerture function
- {
- float calculated_temp; // generating a local variable
- fstream f; // generating a stream for file
- f.open("/sys/bus/iio/devices/iio:device0/in_voltage1_raw"); // config P9_40 AIN of BBBW
- f>>calculated_temp; // giving file address to local variable
- calculated_temp= (calculated_temp/22.75); // formula for calculating temp in celsius
- return (int)calculated_temp; //returning integer value to getTemp function
- }

## Code

- int main()
- { while(1)
- {
- if (getTemp()>= 15 ) {
- pinSetup(pin_number,"out"); //Setting GPIO_67 as output.
- output(pin_number,HIGH); //Sending high (1) logic to GPIO_67.
- cout<<"fan is ON"<<endl;
- system("sleep 1");
- } else {
- pinSetup(pin_number,"out"); //Setting GPIO_67 as output.
- output(pin_number,LOW); //Sending Low(0) logic to GPIO_67
- cout<<"fan is OFF"<<endl;
- system("sleep 1");
- }
- } return 0; }

## output


z

## Reference

- MCT2E information
https://components101.com/ics/mct2e-phototransistor-optocoupler-ic
- LM35 Temperature sensor
https://components101.com/sensors/lm35-temperature-sensor#:~:text=LM35%20is%20a%20precession%20Integrated,C%20to%20150%C2%B0C.&text=There%20will%20be%20rise%20of,degree%20Celsius%20rise%20in%20temperature.

## Referencei

- Connecting with BBBW
- http://exploringbeaglebone.com/chapter6/

## Questions ?

z

## Thanks !

z

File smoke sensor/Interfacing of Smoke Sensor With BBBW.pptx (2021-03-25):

## Interfacing of Smoke Sensor With BBBW

3D cubes suspended in the air

Submitted By
Amit Kumar

## Objectives

Introduction of Smoke Sensor
Requirement
Interfacing with Beaglebone black Wireless
Coding

## Requirement For Task

Smoke Sensor MQ2
Jumper Wires
Beagle bone Black Wireless
A Personal Computer/Laptop

## MQ sensors

Sensor Name | Gas to measure
MQ-2 | Methane, Butane, LPG, Smoke
MQ-3 | Alcohol, Ethanol, Smoke
MQ-4 | Methane, CNG Gas
MQ-5 | Natural gas, LPG
MQ-6 | LPG, butane
MQ-7 | Carbon Monoxide
MQ-8 | Hydrogen Gas
MQ-9 | Carbon Monoxide, flammable gasses
MQ131 | Ozone
MQ135 (https://components101.com/sensors/mq135-gas-sensor-for-air-quality) | Air Quality
MQ136 | Hydrogen Sulphide gas
MQ137 (https://components101.com/sensors/mq137-gas-sensor) | Ammonia
MQ138 | Benzene, Toluene, Alcohol, Propane, Formaldehyde gas, Hydrogen
MQ214 | Methane, Natural Gas
MQ216 | Natural gas, Coal Gas
MQ303A | Alcohol, Ethanol, smoke
MQ306A | LPG, butane
MQ307A | Carbon Monoxide
MQ309A | Carbon Monoxide, flammable gas

## Smoke Sensor MQ2


- MQ2 gas sensor is an electronic sensor used for sensing the concentration of gases in the air such as LPG, propane, methane, hydrogen, alcohol, smoke and carbon monoxide.

## Smoke Sensor

MQ2 gas sensor is also known as chemiresistor. It contains a sensing material whose resistance changes when it comes in contact with the gas. This change in the value of resistance is used for the detection of gas.
MQ2 is a metal oxide semiconductor type gas sensor. Concentrations of gas in the gas is measured using a voltage divider network present in the sensor.
This sensor works on 5V DC voltage. It can detect gases in the concentration of range 200 to 10000ppm.

## Sensitivity of MQ2 sensor


## Internal Circuitry of MQ2


## Part and Materials used in MQ2 sensor

Gas Sensing Layer | SnO2
2.Electrode | Au
3. Electrode Line | Pt
4. Heater Coil | Ni- Cr Alloy
5. Tubular Ceramic | Al2 O3
6. Anti- explosion Network | Stainless steel gauze
7. Clamp ring | Copper Plating Ni
8.Resin Base | Bakelite
9. Tube Pin | Copper Plating Ni

## Internal Parts of MQ2 sensor


## Working Of MQ2 Smoke Sensor

- This sensor contains a sensing element, mainly aluminum-oxide based ceramic, coated with Tin dioxide, enclosed in a stainless-steel mesh. Sensing element has six connecting legs attached to it. Two leads are responsible for heating the sensing element, the other four are used for output signals.
- Oxygen gets adsorbed on the surface of sensing material when it is heated in air at high temperature. Then donor electrons present in tin oxide are attracted towards this oxygen, thus preventing the current flow.

## Working Of MQ2 Smoke Sensor

- When reducing gases are present, these oxygen atoms react with the reducing gases thereby decreasing the surface density of the adsorbed oxygen. Now current can flow through the sensor, which generated analog voltage values.
- These voltage values are measured to know the concentration of gas. Voltage values are higher when the concentration of gas is high.

## Technical Data


## Features of MQ2

Operating Voltage is +5V
Can be used to Measure or detect LPG, Alcohol, Propane, Hydrogen, CO and even methane
Analog output voltage: 0V to 5V
Digital Output Voltage: 0V or 5V (TTL Logic)
Preheat duration 20 seconds
Can be used as a Digital or analog sensor
The Sensitivity of Digital pin can be varied using the potentiometer.

## Pin Configuration of MQ2

Pin No: | Pin Name: | Description
For Module
1 | Vcc | This pin powers the module, typically the operating voltage is +5V
2 | Ground | Used to connect the module to system ground
3 | Digital Out | You can also use this sensor to get digital output from this pin, by setting a threshold value using the potentiometer
4 | Analog Out | This pin outputs 0-5V analog voltage based on the intensity of the gas

## BBBW pin Congiguration


## Connection for interfacing BBBW with MQ2

Pin Vcc of MQ2 module with pin P9_5 or 6 of BBBW
01
Pin GND of MQ2 module with pin P9_45 or 46 of BBBW
02
Pin A0 of MQ2 module with Pin P9_33/35/36/37/38/39/40 of BBW
03

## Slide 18


## Calculation for MQ2 Sensor Data

Each of the gas sensors outputs an analog value from 0 to 4095. To convert this value into voltage, use the following equation.
Sensor Voltage = AnalogReading * 5V / 4095
CO sensor: PPM = 3.027*e^(1.0698*sensor Voltage)

## CO concentration in Air

| Concentration (ppm)
House Without LPG | 0.5 to 5 ppm
House with LPG cooking kit | 5 to 30 ppm
Dangerous Level | > 70 ppm
Fatal Or death level | > 150 ppm

## Coding for Interfacing sensor with BBBW

- #include <iostream> //provides basic input and output services for C++ programs.
- #include <unistd.h> //provides access to the POSIX operating system API.
- #include <fstream> //performs input/output operations on the file
- #include <math.h> // for mathematical operation
- using namespace std;
- int sensor_val() // generating a function for smoke sensor
- {
- int Smoke_sensor; // generating a local variable to store sensor data
- fstream f; // generating a stream for file
- f.open("/sys/bus/iio/devices/iio:device0/in_voltage1_raw"); // config P9_40 AIN of BBBW
- f>>Smoke_sensor; // giving file address to local variable
- return (int)Smoke_sensor; //returning integer value to sensor_val function
- }

## Coding for Interfacing sensor with BBBW

- int main()
- {
- float dex,sensor_output,b ; // declaring local variable
- while(1)
- {
- dex= sensor_val();
- b=dex;
- b=(b/4);
- if ((int)b>=300) // condition for threshold
- cout<< "smoke detected "<< endl;

## Coding for Interfacing sensor with BBBW

- cout<< "smoke detected "<< endl;
- dex=(dex/4096)*5; //converting sensor analog value in voltage
- sensor_output=3.027*exp(1.0698*dex); // sensor output in ppm
- cout<<"Smoke Sensor Data :" << sensor_output <<"ppm"<< endl;
- system("sleep 1"); // putting system to sleep for 1 sec
- }
- return 0;
- }

## OUTPUT on BBBW terminal


## References

- Information about MQ2
https://datasheetspdf.com/pdf/622943/Hanwei/MQ-2/1
https://www.pololu.com/file/0J309/MQ2.pdf
https://components101.com/sensors/mq2-gas-sensor
https://www.google.com/search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

## References

- Interfacing with BBBW
https://www.google.com/search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
https://subscription.packtpub.com/book/hardware_and_creative/9781783986026/1/ch01lvl1sec09/setting-up-the-hardware

## Reference

- CO levels in ppm
https://www.epa.gov/indoor-air-quality-iaq/what-average-level-carbon-monoxide-homes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,be%2030%20ppm%20or%20higher.
https://www.cpsc.gov/Safety-Education/Safety-Education-Centers/Carbon-Monoxide-Information-Center/Carbon-Monoxide-Questions-and-Answers

## Reference

- How to set threshold (https://create.arduino.cc/projecthub/biharilifehacker/how-to-make-smoke-detector-alarm-1c322b?offset=1)val (https://create.arduino.cc/projecthub/biharilifehacker/how-to-make-smoke-detector-alarm-1c322b?offset=1) for sensor (https://create.arduino.cc/projecthub/biharilifehacker/how-to-make-smoke-detector-alarm-1c322b?offset=1)
- https://create.arduino.cc/projecthub/biharilifehacker/how-to-make-smoke-detector-alarm-1c322b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

## Questions?

Question mark on green pastel background

## Thank You!

Magnifying glass on clear background

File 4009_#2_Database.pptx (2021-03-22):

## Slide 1

Developing database for
LCD screen

Sagar Pasricha (C0765531)

## What is database?

- A database is an organized collection of data, generally stored and accessed electronically from a computer system. Where databases are more complex they are often developed using formal design and modeling techniques.
- The database management system (DBMS) is the software that interacts with end users, applications, and the database itself to capture and analyze the data. The DBMS software additionally encompasses the core facilities provided to administer the database. The sum total of the database, the DBMS and the associated applications can be referred to as a "database system".
- Computer scientists may classify database-management systems according to the database models that they support. These models data as rows and columns in a series of tables, and the vast majority use SQL for writing and querying data.

## Mysql

- MySQL is an open-source relational database management system(RDBMS) based on Structured Query Language (SQL).
- It is developed and managed by oracle corporation and initially released on 23 may, 1995.
- It is widely being used in many small and large scale industrial applications and capable of handling a large volume of data.
- After the acquisition of MySQL by Oracle, some issues happened with the usage of the database and hence MariaDB was developed.

## Mariadb

- MariaDB Server is one of the most popular open source relational databases. It’s made by the original developers of MySQL and guaranteed to stay open source.
- It is an open source relational database management system (RDBMS) that is a compatible drop-in replacement for the widely used MySQL database technology.
- It is developed by MariaDB Foundation and initially released on 29 October 2009.
- It has a significantly high number of new features, which makes it better in terms of performance and user-orientation than MySQL.

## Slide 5

- MariaDB is written in C, C++, Perl and Bash languages.
- It was initially released on 2009.
- The performance of MariaDB is far better than MySQL.
- It provides a drop-in replacement for MySQL
- There is no data masking.
- Proprietary code is not accessible in MariaDB.

- MySQL is written in C and C++ languages.
- It was initially released on 1995.
- The performance of MySQL is not that great when compared to MariaDB.
- It does not provide a replacement for MariaDB.
- Data masking is done in MySQL.
- Proprietary code is accessible in MySQL enterprise edition.

Difference between
MariaDB and MySQL

- MariaDB

- MySQL

## Difference between MariaDB and MySQL

- It supports temporary table Space and binary encryption.
- It can handle large-sized data easily.
- Privilege checks are done faster in MariaDB.

- It does not support binary logs or temporary table Space.
- It can not handle large-sized data easily.
- Privilege checks are not that fast in MySQL.

- MariaDB

- MySQL

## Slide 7

Install mariadb on beaglebone

- First update the apt packages index by using following command:
sudo apt update
- Once the packages list is updated, install MariaDB by running the following command:
sudo apt install mariadb-server
- The MariaDB service will start automatically. You can verify it by using folllowing command:
sudo systemctl status mariadb

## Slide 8

Install mariadb on beaglebone


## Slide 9

Verification of mariadb status

- In this step we can check MariaDB is properly installed on beaglebone and to check the status oh MariaDB whether it is active or not.
- For this, we use following command:
sudo systemctl status mariadb

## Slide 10

Verification of mariadb status


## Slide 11

Show databases

You can check the available databases as shown below −
mySQL> SHOW DATABASES;


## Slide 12

Create new database

The mySQL CREATE DATABASE statement is used to create a new mySQL database.
The basic syntax of this CREATE DATABASE statement is as follows −
CREATE DATABASE DatabaseName;
Example:
If you want to create a new database <restaurant_menu>, then the CREATE DATABASE statement would be as shown below −
mySQL> CREATE DATABASE restaurant_menu;

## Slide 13

Create new database


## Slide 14

Use database for further process

The basic syntax of the USE statement is as shown below −
USE DatabaseName;
Example:
> mySQL> use restaurant_menu;

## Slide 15

To get into a database for further process

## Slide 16

Create table in database

- The mySQL CREATE TABLE statement is used to create a new table.
- The basic syntax of the CREATE TABLE statement is as follows −
CREATE TABLE drinks(
-> item varchar(20) not null,
-> price_small varchar(20) not null,
-> price_medium varchar(20) not null,
-> price_large varchar(20) not null,
-> type varchar(20) not null,
-> availability varchar(20) not null);

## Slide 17

Create table in database


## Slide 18

Insert values in table

- The basic syntax of the INSERT INTO statement which are shown below.
INSERT INTO TABLE_NAME value (column1, column2, column3,...columnN);
- Here, column1, column2, column3,...columnN are the names of the columns in the table into which you want to insert the data.
- Example:
INSERT INTO drinks value("mango shake","$2.50", "$3.79", "$4.99", "cold", "no");

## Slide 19

Insert values in table

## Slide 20

Select query to view values inserted in table

- The basic syntax of the SELECT statement is as follows −
- To fetch all the fields available, then you can use the following syntax.
SELECT * FROM table_name;
- Example:
SELECT * FROM drinks;

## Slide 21

Select query to view values inserted in table


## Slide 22

update query in table

- The mySQL UPDATE Query is used to modify the existing records in a table.
- You can use the WHERE clause with the UPDATE query to update the selected rows, otherwise all the rows would be affected.
- Syntax: The basic syntax of the UPDATE query with a WHERE clause is as follows −
UPDATE table_name SET column = value WHERE [condition];
- Example
UPDATE drinks SET price_small="$1.99" WHERE price_small="$2.00";

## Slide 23

update query in table


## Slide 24

Column modification in table

- The mySQL ALTER TABLE command is used to add, delete or modify columns in an existing table.
- You should also use the ALTER TABLE command to add and drop various constraints on an existing table.
- Syntax:
- The basic syntax of an ALTER TABLE command to add a New Column in an existing table is as follows –
ALTER TABLE table_name ADD column_name datatype;
- The basic syntax of an ALTER TABLE command to DROP COLUMN in an existing table is as follows –
ALTER TABLE table_name DROP COLUMN column_name;

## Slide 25

Column modification in table

- The basic syntax of an ALTER TABLE command to change the DATA TYPE of a column in a table is as follows –
ALTER TABLE table_name MODIFY COLUMN column_name datatype;
- The basic syntax of an ALTER TABLE command to add a NOT NULL constraint to a column in a table is as follows -
ALTER TABLE table_name MODIFY column_name datatype NOT NULL;
- Example:
ALTER TABLE drinks MODIFY column price_medium varchar(12) not null;

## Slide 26

update query in table


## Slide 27

references

- What is Database?. Retrieved from en.wikipedia.org
https://en.wikipedia.org/wiki/Database
- Difference between MariaDB and MySQL. Retrieved from geeksforgeeks.org
https://www.geeksforgeeks.org/difference-between-mysql-and-mariadb/
- MariaDB Installation tutorial. Retrieved from linuxize.com
https://linuxize.com/post/how-to-install-mariadb-on-debian-9/
- Database development tutorial. Retrieved from tutorialspoint.com
https://www.tutorialspoint.com/sql/sql-alter-command.htm

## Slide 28

Any questions?

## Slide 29

Thank you

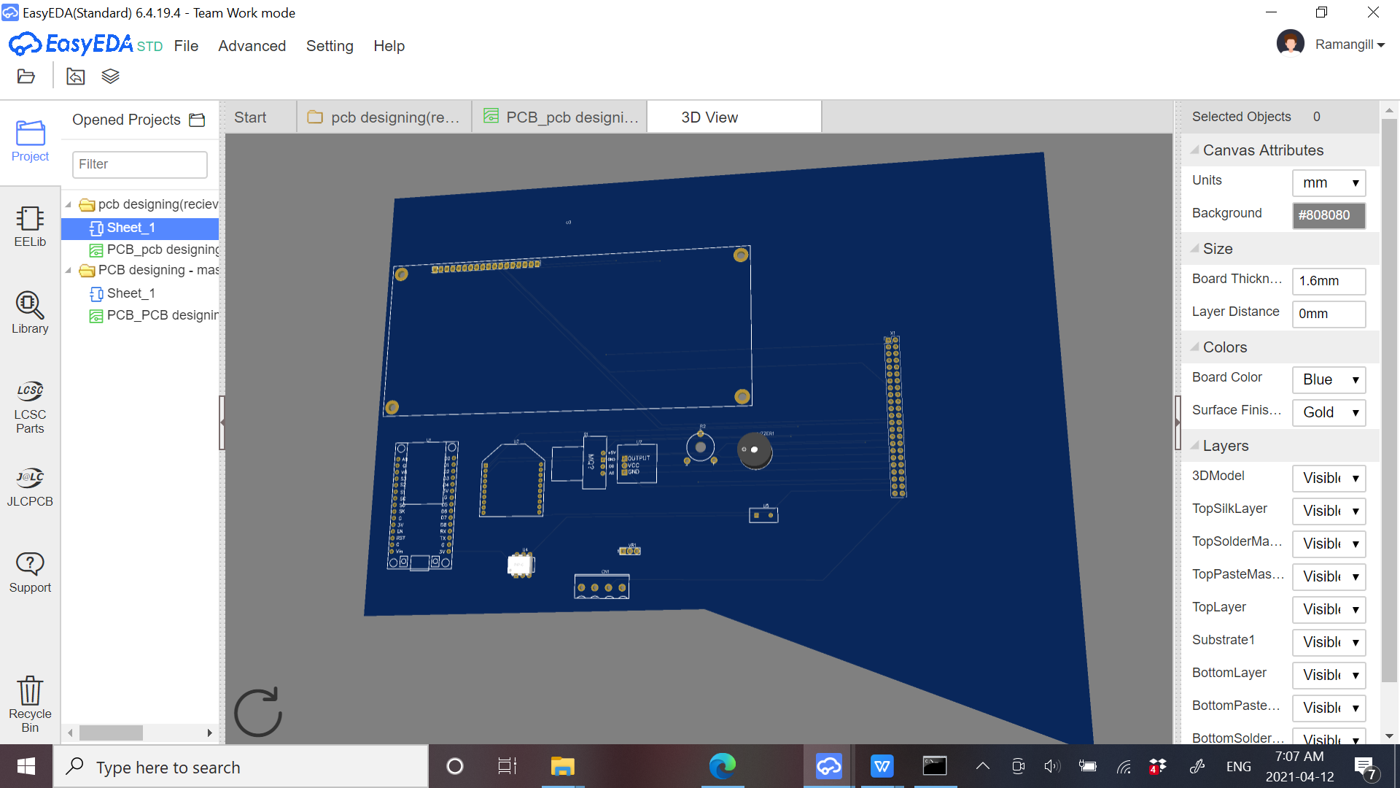
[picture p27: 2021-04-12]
PCB designing of reciever side/3D view (top view).png

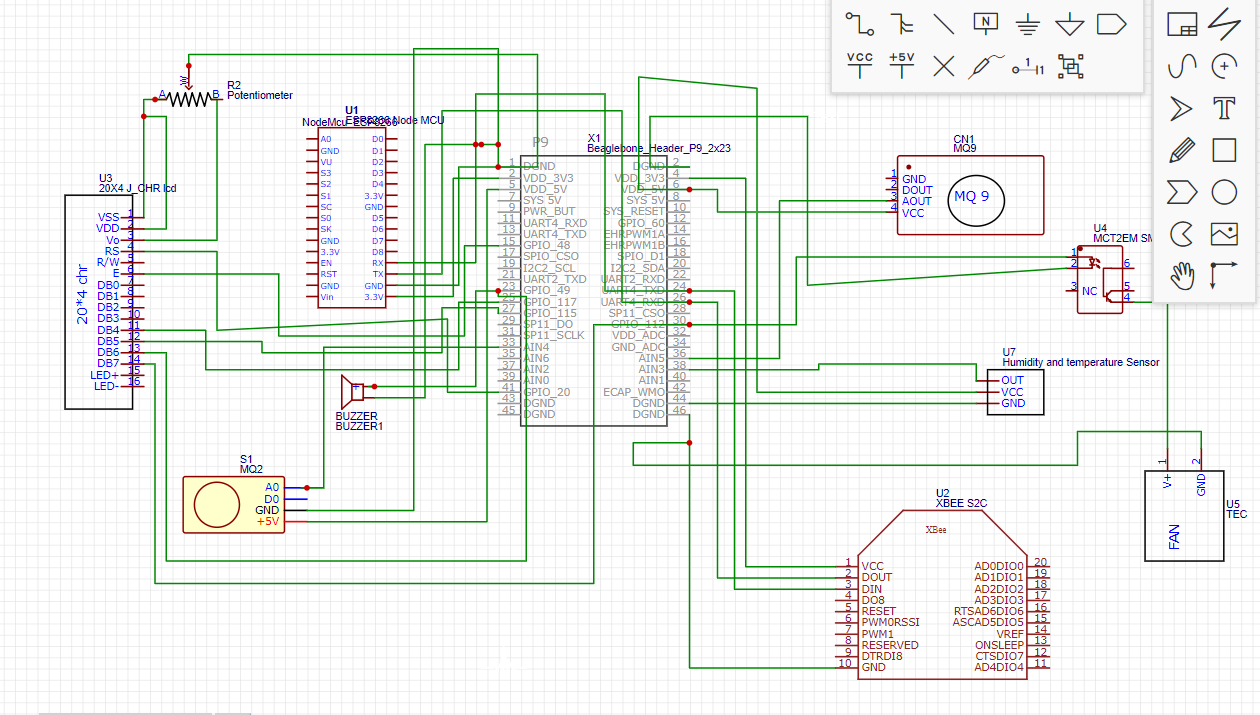
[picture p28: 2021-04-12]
PCB designing of reciever side/PCB Designing of receiver side.PNG

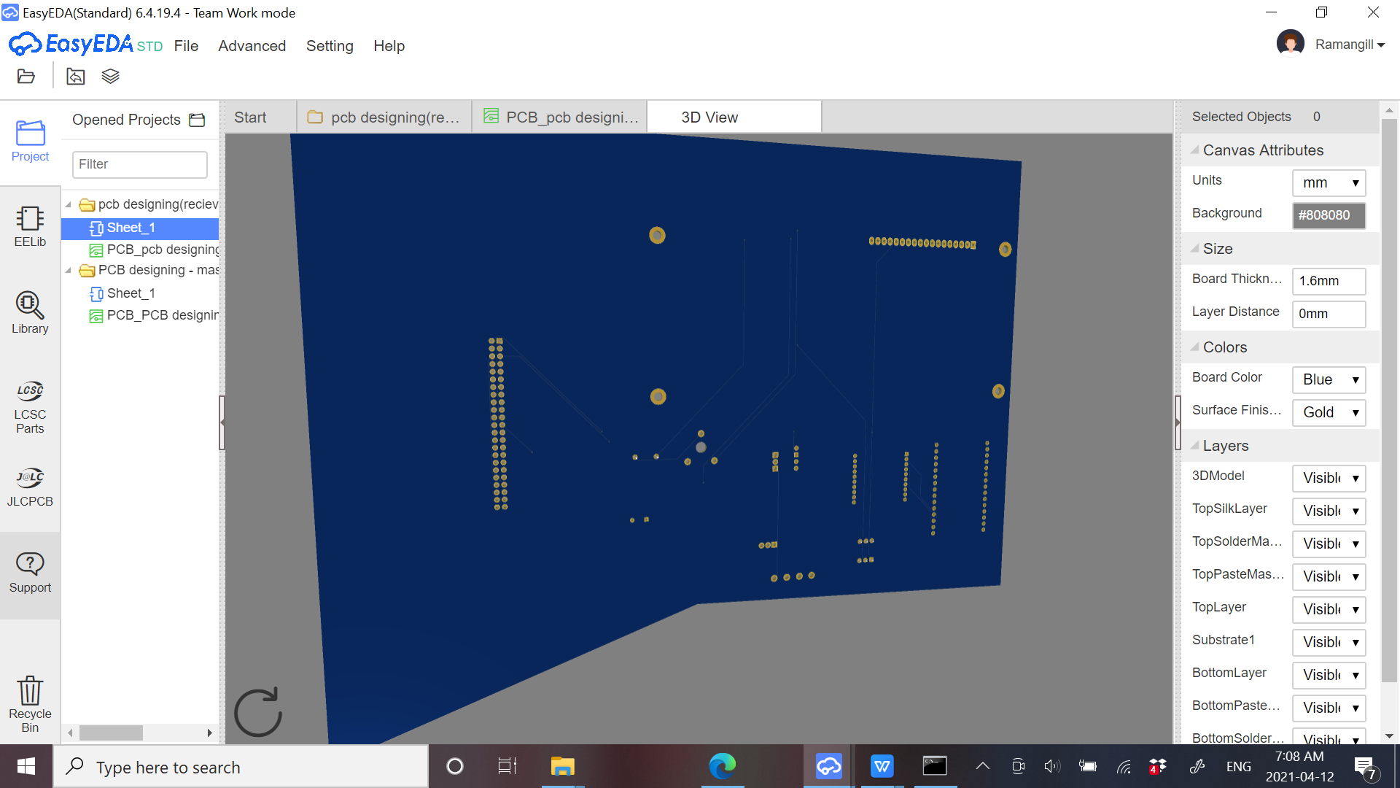
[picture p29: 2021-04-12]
PCB designing of reciever side/3D View(bottom view).png

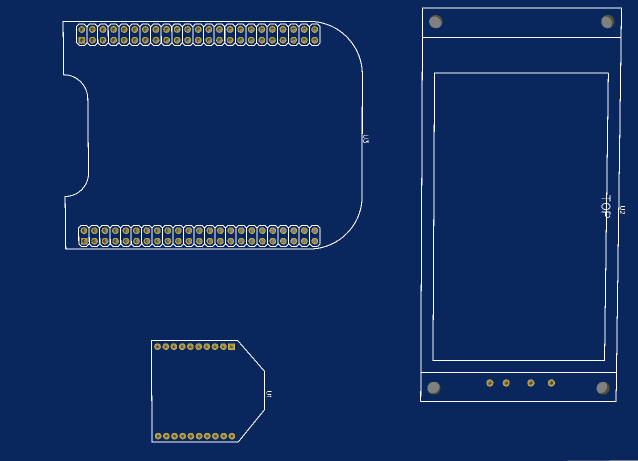
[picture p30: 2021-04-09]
3d_top_pcb_tx.PNG

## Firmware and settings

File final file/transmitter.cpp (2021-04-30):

#include <fcntl.h>
#include <cstring>
#include <cstdlib>
#include <sstream>
#include <map>
#include <unistd.h>
#include <termios.h>
#include <iostream>
//#include <mysql.h>
#include <stdio.h>
#include <stdlib.h>
#include <fstream>
#include "SocketClient.h"
#include <vector>
#include <bits/stdc++.h>
#include <boost/algorithm/string.hpp>

using namespace std;
using namespace boost;
using namespace thingSpeak;

string thingSpeak_key="49ZOKETVBQLQUUWK";

class Uart{
    private:
        string portname;
        size_t baud_rate;
        int    file_descriptor;
        int    byte_counter;

    public:
        Uart(string portname, size_t baud_rate){
            this->portname=portname;
            this->baud_rate=baud_rate;
            file_descriptor=open(this->portname.c_str(), O_RDWR);
            
            if(file_descriptor<0){
                cout<<"Port is Busy or Can't open for communication !!";
                exit(0);
            } else {
                cout<<"Connection Succeed!!"<<endl;
            }

            struct termios options;

            tcgetattr(file_descriptor, &options);
            options.c_cflag &= ~PARENB; // Clear parity bit, disabling parity (most common)
            options.c_cflag &= ~CSTOPB; // Clear stop field, only one stop bit used in communication (most common)
            options.c_cflag &= ~CSIZE; // Clear all bits that set the data size 
            options.c_cflag |= CS8; // 8 bits per byte (most common)
            options.c_cflag &= ~CRTSCTS; // Disable RTS/CTS hardware flow control (most common)
            options.c_cflag |= CREAD | CLOCAL; // Turn on READ & ignore ctrl lines (CLOCAL = 1)

            options.c_lflag &= ~ICANON;
            options.c_lflag &= ~ECHO; // Disable echo
            options.c_lflag &= ~ECHOE; // Disable erasure
            options.c_lflag &= ~ECHONL; // Disable new-line echo
            options.c_lflag &= ~ISIG; // Disable interpretation of INTR, QUIT and SUSP
            options.c_iflag &= ~(IXON | IXOFF | IXANY); // Turn off s/w flow ctrl
            options.c_iflag &= ~(IGNBRK|BRKINT|PARMRK|ISTRIP|INLCR|IGNCR|ICRNL); // Disable any special handling of received bytes

            options.c_oflag &= ~OPOST; // Prevent special interpretation of output bytes (e.g. newline chars)
            options.c_oflag &= ~ONLCR; // Prevent conversion of newline to carriage return/line feed
            // tty.c_oflag &= ~OXTABS; // Prevent conversion of tabs to spaces (NOT PRESENT ON LINUX)
            // tty.c_oflag &= ~ONOEOT; // Prevent removal of C-d chars (0x004) in output (NOT PRESENT ON LINUX)

            options.c_cc[VTIME] = 5;    // Wait for up to 1s (10 deciseconds), returning as soon as any data is received.
            options.c_cc[VMIN] = 0;

            // Set in/out baud rate to be 9600
            cfsetispeed(&options, this->baud_rate);
            cfsetospeed(&options, this->baud_rate);
            // options.c_cflag = this->baud_rate | CS8 | CREAD | CLOCAL;
            // options.c_cflag &= ~CRTSCTS;
            // options.c_iflag = IGNPAR | ICRNL;
            // options.c_iflag &= ~(IGNBRK|BRKINT|PARMRK|ISTRIP|INLCR|IGNCR|ICRNL);
            // options.c_oflag &= ~OPOST;
            // options.c_oflag &= ~ONLCR;

            tcsetattr(file_descriptor, TCSANOW, &options);

        }
        ~Uart(){
            close(this->file_descriptor);
            cout<<"Connection Closed !!"<<endl;
        }

        string readline(){
            char recieve[80];
            char* data=(char *)"\0";
            memset(&recieve, '\0', sizeof(recieve));
            int array_size=sizeof(recieve) / sizeof(char);
            this->byte_counter=read(file_descriptor, &recieve, sizeof(recieve));
            if(this->byte_counter>0){
                data = (char *) malloc(this->byte_counter*sizeof(char));
                data=recieve;
                return data;
            }
            string temp(data);
            return temp;
      }
      void writeData(string data){
             write(file_descriptor, data.c_str(), data.length());
      }
};

map<string,string> foodDict={
    {"PZA","Pizza"},
    {"BGR","Burger"},
    {"ICM","Ice Cream"},
    {"COF","Coffee"}
};

vector<string> container;
vector<string> price;
int totalPrice;

//void finish_with_error(MYSQL *con)
//{
  //fprintf(stderr, "%s\n", mysql_error(con));
  //mysql_close(con);
 // exit(1);
//}

string mapping(string input){
    for(auto iter: foodDict){
        // cout<<iter.second;
        string key=iter.first;
        string value=iter.second;
        int index=input.find(key);
        if(index <= input.length()){
            input.replace(index,input.length(),value);
        }
    }
    return input;
    
}

void speak(int amount, int qty){
   ostringstream head, data;
   cout << "Starting ThingSpeak Example" << endl;
   SocketClient sc("api.thingspeak.com",80);
   data << "field1="<<amount<<"&field2=" << qty << endl;
   sc.connectToServer();
   head << "POST /update HTTP/1.1\n"
        << "Host: api.thingspeak.com\n"
        << "Connection: close\n"
        << "X-THINGSPEAKAPIKEY: " + thingSpeak_key +"\n"
        << "Content-Type: application/x-www-form-urlencoded\n"
        << "Content-Length:" << string(data.str()).length() << "\n\n";
   sc.send(string(head.str()));
   sc.send(string(data.str()));
   string rec = sc.receive(1024);
//    cout << "[" << rec << "]" << endl;
   cout << "End of ThingSpeak Example" << endl;
}


int main(int argc, char **argv){
    ////MYSQL *con = mysql_init(NULL);
    //if (con == NULL)
    //{
      //  fprintf(stderr, "%s\n", mysql_error(con));
       // exit(1);
  //  }

    //if (mysql_real_connect(con, "localhost", "root", "Test@1234",
     //       "orders", 0, NULL, 0) == NULL){
      //  finish_with_error(con);
    //}
    string nextionString,dataContainer,tempp;
    int quantity=0,prices=0,totalQty=0;
    vector<string> tempCnt;
    Uart nextion("/dev/ttyO4",B9600);
    Uart xbee("/dev/ttyO1",B9600);
    
    while(true){
        nextionString=nextion.readline();
        tempCnt.clear();
        // cin>>nextionString;
        
        if(nextionString=="confirm") {
            boost::split(container, dataContainer, boost::is_any_of("="));
            container.erase(container.begin());
            string tempData="";
            for(string a:container){
                boost::split(price, a, boost::is_any_of("|"));
                // price.pop_back();
                // int count=0;
                // for(string b:price){
                //     if(count==1){
                //         stringstream conv(b);
                //         conv >> prices;
                //         conv.str("");
                //         totalPrice+=quantity*prices;
                //         break;
                //     }
                //     stringstream conv(b);
                //     conv >> quantity;
                //     conv.str("");
                //     ++count;
                // }
                string tempp=mapping(a);
                vector<string> tempCnt;
                boost::split(tempCnt, tempp, boost::is_any_of("|"));
	        stringstream co(tempCnt[0]);
                int dum;
                co >> dum;
                co.str("");
                co.clear();
                totalQty+=dum;

                string qry="insert into food_order(item,qty,price) values('"+tempCnt[2]+"',"+tempCnt[0]+","+tempCnt[1]+")";            
                stringstream conv(tempCnt[0]);
                conv >> quantity;
    		conv.str("");
		conv.clear();
		//if (mysql_query(con, qry.c_str())){
                   // finish_with_error(con);
                //}//
                tempData+="="+tempp;
                
            }
            cout<<tempData<<endl;
            if(totalPrice>0){
		cout<<"Amit"<<endl;
		speak(totalPrice,totalQty);
                xbee.writeData(tempData);
		totalQty=0;
            }
            cout<<"Amount : "<<totalPrice<<endl;
            cout<<"Reciever : "<<tempData<<endl;
        }
        else if(nextionString.length()!=0){
            dataContainer=nextionString;
	    cout<<dataContainer<<endl;
            boost::split(container, dataContainer, boost::is_any_of("="));
            container.erase(container.begin());
            string tempData="";
            totalPrice=0;
            for(string a:container){
                boost::split(price, a, boost::is_any_of("|"));
                price.pop_back();
                int count=0;

                for(string b:price){
                    if(count==1){
                        stringstream conv(b);
                        conv >> prices;
                        conv.str("");
                        totalPrice+=quantity*prices;
                        break;
                    }
                    stringstream conv(b);
                    conv >> quantity;
                    conv.str("");
                    ++count;
                }
                // string tempp=mapping(a);
                // vector<string> tempCnt;
                // boost::split(tempCnt, tempp, boost::is_any_of("|"));
                // string qry="insert into food_order(item,qty,price) values('"+tempCnt[2]+"',"+tempCnt[0]+","+tempCnt[1]+")";            
                // if (mysql_query(con, qry.c_str())){
                //     finish_with_error(con);
                // }
                // tempData+="="+tempp;
            }
            cout<<tempData<<endl;
            if(totalPrice>0){
                // speak(totalPrice);
                stringstream ss;
                ss << totalPrice;
                string sendNextion="python3 /home/debian/demoFolder/price_calculator.py "+ss.str();
                ss.str("");
                ss.clear();
                system(sendNextion.c_str());
            }
            }

        }
        // sleep(1);
        // fflush(stdout);
   // mysql_close(con);

    return 0;
}


// `mysql_config --cflags --libs`

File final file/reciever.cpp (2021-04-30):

#include <fcntl.h>
#include <cstring>
#include <cstdlib>
#include <unistd.h>
#include <termios.h> 
#include <iostream>
#include <sstream>
#include <fstream>
#include <cstring>
#include <unistd.h>
#include <math.h>  // for mathematical operation
#include "SocketClient.h"
#include <vector>
#include <bits/stdc++.h>
#include <boost/algorithm/string.hpp>


#define LOW 0
#define HIGH 1

using namespace std;
using namespace thingSpeak;

int fanPin=66;
int button=47;
int buzzeR=27;

ostringstream out_string;
string PATH="/sys/class/gpio/gpio";
fstream fd;

string thingSpeak_key="YHOLRJA0W7XREL23";
string smokeTField="field4";
string gasTField="field5";
string tempTField="field3";

// http://web.alfredstate.edu/faculty/weimandn/lcd/lcd_addressing/lcd_addressing_index.html
// https://github.com/adafruit/Adafruit_Python_CharLCD/blob/master/Adafruit_CharLCD/Adafruit_CharLCD.py
// https://www.arduino.cc/en/Tutorial/LibraryExamples/HelloWorld


//Commands
#define LCD_CLEARDISPLAY    0x01
#define LCD_RETURNHOME      0x02
#define LCD_ENTRYMODESET    0x04
#define LCD_DISPLAYCONTROL  0x08
#define LCD_CURSORSHIFT     0x10
#define LCD_FUNCTIONSET     0x20
#define LCD_SETCGRAMADDR    0x40
#define LCD_SETDDRAMADDR    0x80

//Entry flags
#define LCD_ENTRYRIGHT      0x00
#define LCD_ENTRYLEFT       0x02
#define LCD_ENTRYSHIFTINCREMENT 0x01
#define LCD_ENTRYSHIFTDECREMENT 0x00

//Control flags
#define LCD_DISPLAYON   0x04
#define LCD_DISPLAYOFF  0x00
#define LCD_CURSORON    0x02
#define LCD_CURSOROFF   0x00
#define LCD_BLINKON     0x01
#define LCD_BLINKOFF    0x00

//Move flags
#define LCD_DISPLAYMOVE     0x08
#define LCD_CURSORMOVE      0x00
#define LCD_MOVERIGHT       0x04
#define LCD_MOVELEFT        0x00

//Function set flags
#define LCD_8BITMODE  0x10
#define LCD_4BITMODE  0x00
#define LCD_2LINE     0x08
#define LCD_1LINE     0x00
#define LCD_5x10DOTS  0x04
#define LCD_5x8DOTS   0x00

//Offset for up to 4 rows.
int LCD_ROW_OFFSETS[]= {0x00, 0x40, 0x14, 0x54};

//Char LCD plate GPIO numbers.
#define LCD_PLATE_RS     15
#define LCD_PLATE_RW     14
#define LCD_PLATE_EN     13
#define LCD_PLATE_D4     12
#define LCD_PLATE_D5     11
#define LCD_PLATE_D6     10
#define LCD_PLATE_D7     9
#define LCD_PLATE_RED    6
#define LCD_PLATE_GREEN  7
#define LCD_PLATE_BLUE   8

//Char LCD plate button names.
#define SELECT      0
#define RIGHT       1
#define DOWN        2
#define UP          3
#define LEFT        4


class LiquidCrystal{
    private:
        int _cols, _lines, _rs, _en, _d4, _d5, _d6, _d7, display_control, display_function, display_mode, _backlight;
        ostringstream out_string;
        string PATH = "/sys/class/gpio/gpio";
        fstream fd;

    public:
        void pinSetup(int pinNumber){
            out_string << pinNumber;
            string newS=PATH+out_string.str();
            out_string.str("");
            out_string.clear();
            fd.open(newS+"/direction");
            fd << "out";
            fd.close();
        }
        
        void outputs(int pinNumber, int val){
            out_string << pinNumber;
            string newS=PATH+out_string.str();
            out_string.str("");
            out_string.clear();
            out_string << val;
            fd.open(newS+"/value");
            fd << val;
            out_string.str("");
            out_string.clear();
            fd.close();    
        }

        void output(int pinNumber, bool logic){
            out_string << pinNumber;
            string newS=PATH+out_string.str();
            out_string.str("");
            out_string.clear();
            out_string << int(logic);
            fd.open(newS+"/value");
            fd << int(logic);
            out_string.str("");
            out_string.clear();
            fd.close();
        }


        void home(){
            /* Move the cursor back to its home (first line and first column).*/

            write8(LCD_RETURNHOME); // set cursor position to zero
            _delay_microseconds(3000);  // this command takes a long time!
        }

        void clear(){
            /* Clear the LCD.*/

            write8(LCD_CLEARDISPLAY);  // command to clear display
            _delay_microseconds(2000);  // 3000 microsecond sleep, clearing the display takes a long time
        }

        void _delay_microseconds(float tim){
            tim/=50000;
            out_string << tim;
            string cmd="sleep "+out_string.str();
            out_string.str("");
            out_string.clear();
            system(cmd.c_str());
        }

        void set_cursor(int col, int row){
            /* Move the cursor to an explicit column and row position. */

            // Clamp row to the last row of the display.

            if(row > _lines)
                row = _lines - 1;
            // Set location.
            
            write8(LCD_SETDDRAMADDR | (col + LCD_ROW_OFFSETS[row]));
        }

        void enable_display(int enable){
            /* Enable or disable the display.  Set enable to True to enable.*/

            if(enable)
                display_control |= LCD_DISPLAYON;
            else
                display_control &= ~LCD_DISPLAYON;
            write8(LCD_DISPLAYCONTROL | display_control);
        }

        void _pulse_enable(){
        // Pulse the clock enable line off, on, off to send command.
             output(_en, false);
             _delay_microseconds(1);      // 1 microsecond pause - enable pulse must be > 450ns
             output(_en, true);
             _delay_microseconds(1);      // 1 microsecond pause - enable pulse must be > 450ns
             output(_en, false);
             _delay_microseconds(1);
        }

        void show_cursor(bool show){
        /* Show or hide the cursor.  Cursor is shown if show is True.*/ 
            if(show)
                display_control |= LCD_CURSORON;
            else{
                display_control &= ~LCD_CURSORON;
                write8(LCD_DISPLAYCONTROL | display_control);
            }
        }

        void blink(bool blink){
            /* Turn on or off cursor blinking.  Set blink to True to enable blinking.*/
            if(blink)
                display_control |= LCD_BLINKON;
            else
                display_control &= ~LCD_BLINKON;
            write8(LCD_DISPLAYCONTROL | display_control);
        }

        void move_left(){
            /* Move display left one position.*/
            write8(LCD_CURSORSHIFT | LCD_DISPLAYMOVE | LCD_MOVELEFT);
        }

        void move_right(){
            /* Move display right one position.*/

            write8(LCD_CURSORSHIFT | LCD_DISPLAYMOVE | LCD_MOVERIGHT);
        }

        void set_left_to_right(){
            /* Set text direction left to right.*/

            display_mode |= LCD_ENTRYLEFT;
            write8(LCD_ENTRYMODESET | display_mode);
        }
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

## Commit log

2021-04-12 Create PCB designing of reciever side
2021-04-19 Create 0 pcb implementation on receiver side
